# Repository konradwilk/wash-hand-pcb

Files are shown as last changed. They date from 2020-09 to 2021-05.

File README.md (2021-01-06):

# License

The project is under Attribution-ShareAlike 4.0 International (CC BY-SA 4.0).

# Libraries used for this project

 - adafruit
 - darnok\_common (https://github.com/konradwilk/eagle-libraries.git)
 - darnok\_led (https://github.com/konradwilk/eagle-libraries.git)
 - darnok\_usb (https://github.com/konradwilk/eagle-libraries.git)
 - darnok\_sensors (https://github.com/konradwilk/eagle-libraries.git)
 - darnok\_microsd (https://github.com/konradwilk/eagle-libraries.git)
 - darnok\_4050 (https://github.com/konradwilk/eagle-libraries.git)
 - SparkFun-Aesthetics
 - SparkFun-Capacitors
 - SparkFun-Connectors
 - SparkFun-Hardware
 - SparkFun-IC-Microcontroller
 - SparkFun-IC-Power
 - SparkFun-Jumpers
 - Serial-Basic (https://github.com/sparkfun/Serial_Basic_Breakout-CH340G.git)

# Purpose

Quite simply it is to have a count-down timer for 20 seconds for washing hands.
It is activated by a line sensor (which has infrared light) that plugs in the board.

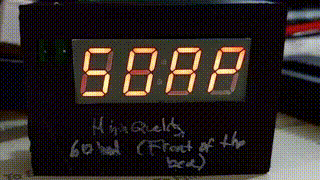
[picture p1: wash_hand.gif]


Video (speed up) of text printed.

# PCB

The _main_ branch is for development and changes often.
The <a href="Wash_Hand.pdf">Wash Hand</a> Board and Schematic are available.

## Prior versions

There are various branches, see:

 - <a href="https://github.com/konradwilk/wash-hand-pcb/tree/stable-1.3-tqfp">stable-1.3-tqfp</a>
 - <a href="https://github.com/konradwilk/wash-hand-pcb/tree/stable-1.3-dip28">stable-1.3-dip28</a>
 - <a href="https://github.com/konradwilk/wash-hand-pcb/tree/stable-1.2-dip28">stable-1.2-dip28</a>

# Future plans for software

In particular order:

 - Fetch data from a SD-card (if attached), otherwise read from EEPROM (1K).
 - Format-type of the data type for above mechanism.
 - Utilize sleep operations to keep the CPU most of the time asleep.
 - Utilize modulo for the numbers.

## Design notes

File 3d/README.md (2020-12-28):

# Create a board outline STL file
 
The release.sh release creates a SVG (and BMP) file which
has the outline of the board.

This can converted to STL files for helping to create
a box for it.

The sequence is as follow:

- Install Inkscape 0.92 (don't use 1.01) as the extension does not work
  with later versions.

- Install in .config/inkscape/extensions the
  https://github.com/l0b0/paths2openscad.git extension
  (the .py and .inx file).

- In Inkscape import the SVG file (created from the
  release.sh - the h-<release>.svg file. (See Wash_Hand_dim.svg)

- Select All

- Object|Ungroup

- Extensions|Generate from Path|Paths to OpenSCAD
- Output file Wash_Hand_dim.scad, keep the defaults, let it rip

- In OpenSCAD, load it, edit it (change height, etc) and render (F6) it,
  and Export as STL (F7) as Wash_Hand_dim.stl

- Then you have a 3D-ish presentation of what outline of the board
  and can use it to create boxes for the board.

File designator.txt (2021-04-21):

Y1
LED1
C14
C12
C13
Y2
RX
TX
R20
R19
R16
C4
C3
C16
C15
R9
R15
R1
R2
R3
R4
R5
R6
R7
R14
R12
TM1
IC1
R17
U2
LED2
T1
U1
U$4

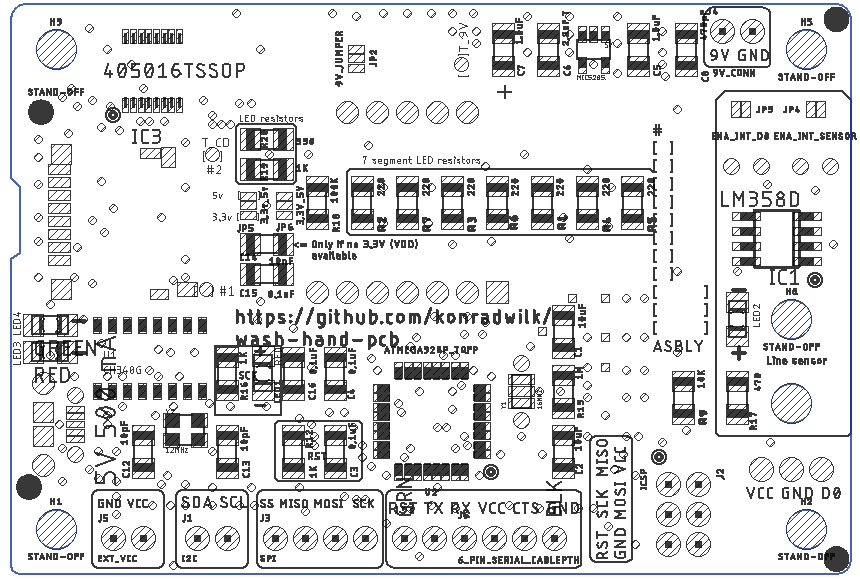
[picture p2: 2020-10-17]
v1.4-rc1/t-v1.4-rc1.png

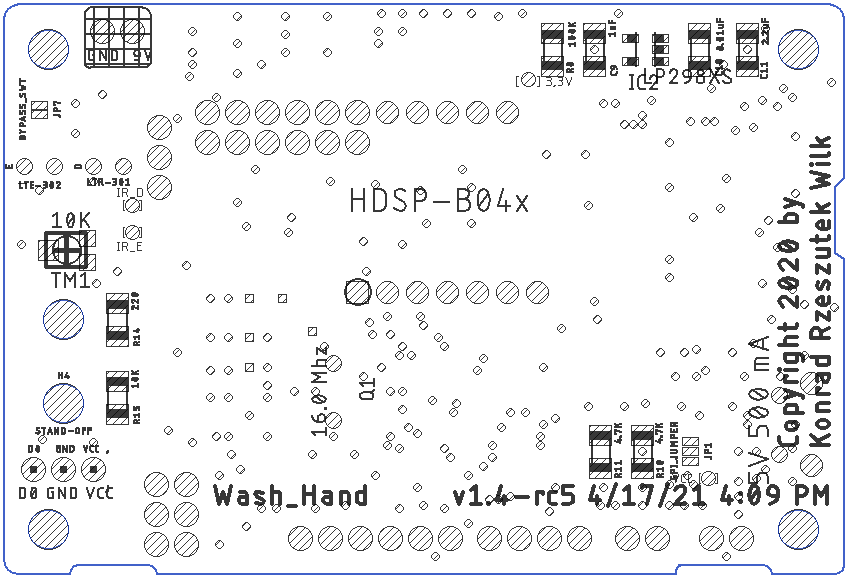
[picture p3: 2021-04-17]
v1.4-rc5/b-v1.4-rc5.png

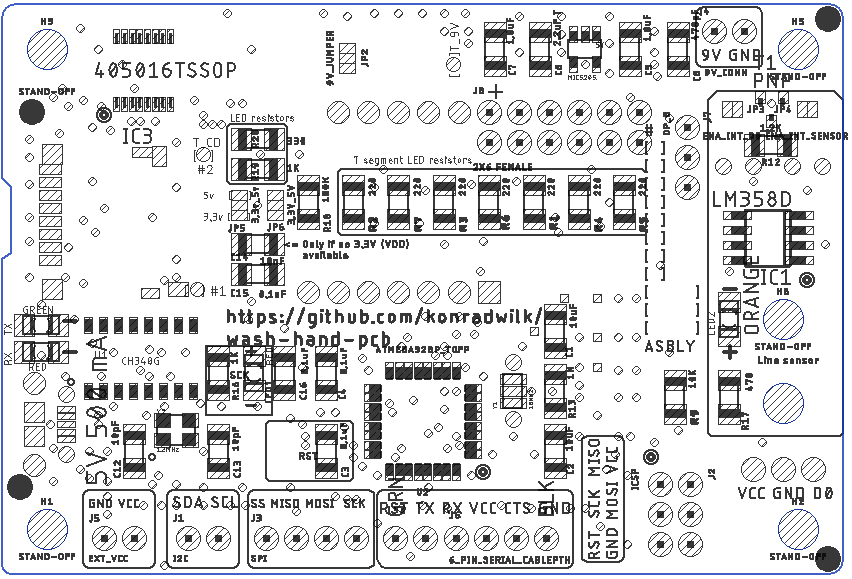
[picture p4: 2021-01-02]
v1.4-rc4/t-v1.4-rc4.png

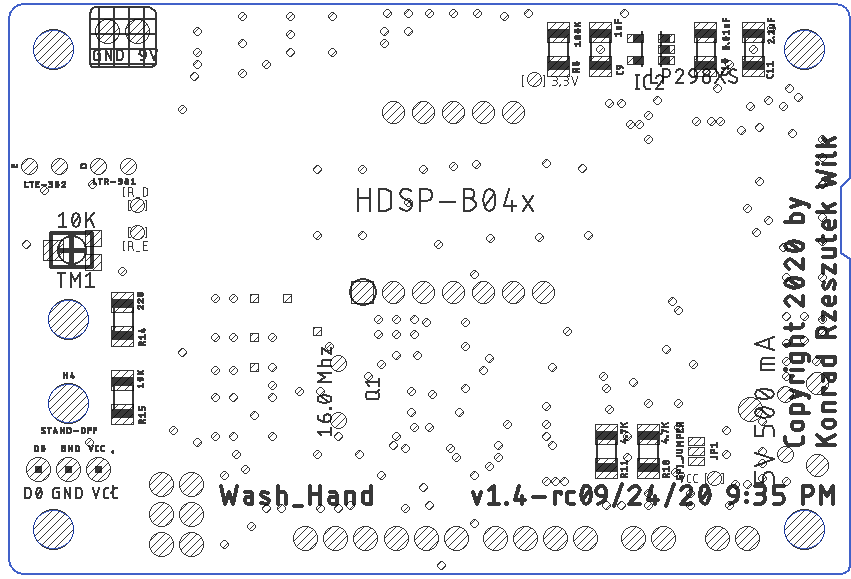
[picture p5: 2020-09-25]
v1.4-rc0/b-v1.4-rc0.png

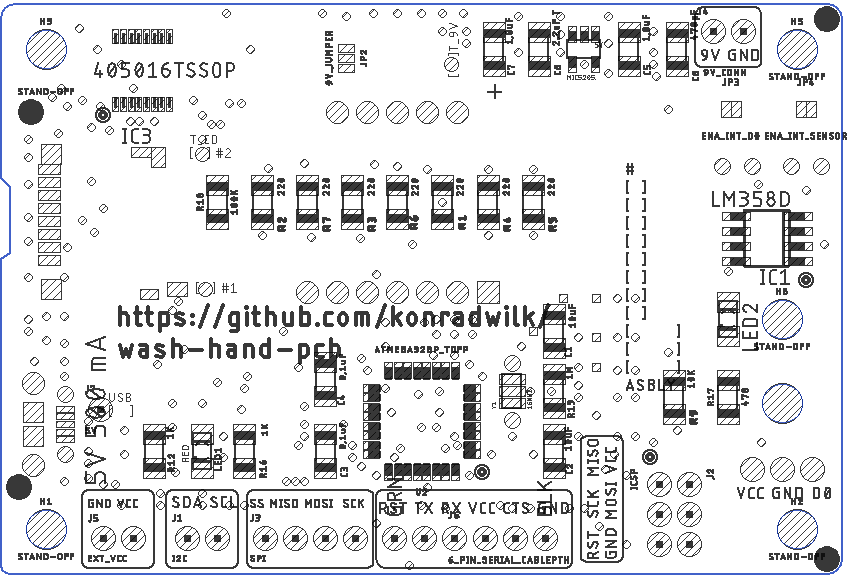
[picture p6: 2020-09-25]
v1.4-rc0/t-v1.4-rc0.png

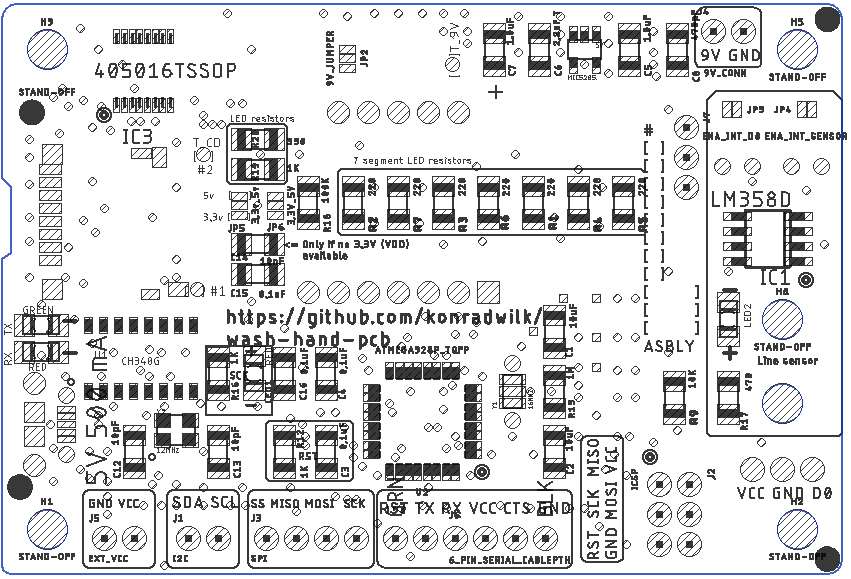
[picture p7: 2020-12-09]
v1.4-rc2/t-v1.4-rc2.png

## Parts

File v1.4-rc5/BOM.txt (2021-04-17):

Partlist exported from /home/konrad/eagle-projects/COVID19-WashHands/Hardware/Wash_Hand.sch at 4/17/21 4:09 PM

Qty Value                        Device                       Package                      Parts                           Description                                                                                                                                                                                                                                             HDSP-B04E MF MPN         OC_FARNELL OC_NEWARK POPULARITY PROD_ID    VALUE          
1   0.01uF                       1.0UF-1206-50V-10%           1206                         C10                             1µF ceramic capacitors                                                                                                                                                                                                                                                                                           CAP-09822  1.0uF          
2   0.1uF                        1.0UF-1206-50V-10%           1206                         C3, C4                          1µF ceramic capacitors                                                                                                                                                                                                                                                                                           CAP-09822  1.0uF          
2   0.1uF                        10UF-1206-6.3V-20%           1206                         C15, C16                        10.0µF ceramic capacitors                                                                                                                                                                                                                                                                                        CAP-10057  10uF           
1   1.2K                         RESISTORR1206                1206                         R12                                                                                                                                                                                                                                                                                                                                                                        
2   100K                         RESISTORR1206                1206                         R8, R18                                                                                                                                                                                                                                                                                                                                                                    
2   10K                          RESISTORR1206                1206                         R9, R15                                                                                                                                                                                                                                                                                                                                                                    
1   10K                          TRIMPOTTC33X                 TC33X                        TM1                             SMT trimmer potentiometer part number TC33X                                                                                                                                                                                                                                                                                                
1   10nF                         10UF-1206-6.3V-20%           1206                         C14                             10.0µF ceramic capacitors                                                                                                                                                                                                                                                                                        CAP-10057  10uF           
4   10pF                         10UF-1206-6.3V-20%           1206                         C1, C2, C12, C13                10.0µF ceramic capacitors                                                                                                                                                                                                                                                                                        CAP-10057  10uF           
1   114-00841-68                 114-00841-68                 114-00841-68                 MICROSD                         Amphenol MicroSD Push Pull                                                                                                                                                                                                                                                                                                                 
1   12MHz                        CRYSTAL-GROUNDED3.2X2.5      CRYSTAL-SMD-3.2X2.5          Y2                              Small, 3.2x2.5mm, SMD Crystal                                                                                                                                                                                                                                                                                    XTAL-13518 12MHz          
1   16.0 Mhz                     CRYSTALHC49S                 HC49/S                       Q1                              CRYSTAL                                                                                                                                                                                                                                                                          1667008    unknown                                        
1   16MHZ                        RESONATORMU                  RESONATOR                    Y1                                                                                                                                                                                                                                                                                                                                                                         
2   1K                           RESISTORR1206                1206                         R16, R19                                                                                                                                                                                                                                                                                                                                                                   
1   1M                           RESISTORR1206                1206                         R13                                                                                                                                                                                                                                                                                                                                                                        
3   1uF                          1.0UF-1206-50V-10%           1206                         C5, C7, C9                      1µF ceramic capacitors                                                                                                                                                                                                                                                                                           CAP-09822  1.0uF          
1   2.2uF                        1.0UF-1206-50V-10%           1206                         C11                             1µF ceramic capacitors                                                                                                                                                                                                                                                                                           CAP-09822  1.0uF          
1   2.2uF T                      1.0UF-1206-50V-10%           1206                         C6                              1µF ceramic capacitors                                                                                                                                                                                                                                                                                           CAP-09822  1.0uF          
8   220                          RESISTORR1206                1206                         R1, R2, R3, R4, R5, R6, R7, R14                                                                                                                                                                                                                                                                                                                                            
1   2X6 FEMALE                   CONN_06X2PTH_FEMALE          2X6                          J8                              Multi connection point. Often used as Generic Header-pin footprint for 0.1 inch spaced/style header connections                                                                                                                                                                                                  CONN-12423 2X6 FEMALE     
1   3.3V_5V                      JUMPER-SMT_3_2-NC_PASTE_SILK SMT-JUMPER_3_2-NC_PASTE_SILK JP6                             Normally closed solder jumper (2 of 2 connections)                                                                                                                                                                                                                                                                                         
1   3.3v_5v                      JUMPER-SMT_3_2-NC_PASTE_SILK SMT-JUMPER_3_2-NC_PASTE_SILK JP5                             Normally closed solder jumper (2 of 2 connections)                                                                                                                                                                                                                                                                                         
1   330                          RESISTORR1206                1206                         R20                                                                                                                                                                                                                                                                                                                                                                        
2   4.7K                         RESISTORR1206                1206                         R10, R11                                                                                                                                                                                                                                                                                                                                                                   
1   405016TSSOP                  405016TSSOP                  TSSOP16                      IC3                             Hex non-inverting BUFFER                                                                                                                                                                                                                                                                                                                   
1   470                          RESISTORR1206                1206                         R17                                                                                                                                                                                                                                                                                                                                                                        
1   470pF                        1.0UF-1206-50V-10%           1206                         C8                              1µF ceramic capacitors                                                                                                                                                                                                                                                                                           CAP-09822  1.0uF          
1   5V                           V_REG_MIC52055V              SOT23-5                      MIC5205                         V_REG MIC5205 Standard 3.3V, 5V, and Adjustable 150mA LDO voltage regulator in SOT-23 layout. Micrel part MIC5205. BP (by-pass) pin is used to lower output noise with 470pF cap, may be left open. On the adjustable version BP is used to set output.                                                          VREG-00823 5V             
1   6_PIN_SERIAL_CABLEPTH        6_PIN_SERIAL_CABLEPTH        FTDI_BASIC                   J6                              6-pin header connection for use with the "FTDI BASIC" pinout - CABLE SIDE.                                                                                                                                                                                                                                                                 
1   9V_CONN                      CONN_02                      1X02                         J4                              Multi connection point. Often used as Generic Header-pin footprint for 0.1 inch spaced/style header connections                                                                                                                                                                                                                            
1   9V_JUMPER                    JUMPER-SMT_3_2-NC_PASTE_SILK SMT-JUMPER_3_2-NC_PASTE_SILK JP2                             Normally closed solder jumper (2 of 2 connections)                                                                                                                                                                                                                                                                                         
1   ATMEGA328P_TQFP              ATMEGA328P_TQFP              TQFP32-08                    U2                              Popular 328P in QFP                                                                                                                                                                                                                                                                                              IC-09069   ATMEGA328P_TQFP
1   BYPASS_SWT                   JUMPER-SMT_2_NO_SILK         SMT-JUMPER_2_NO_SILK         JP7                             Normally open jumper                                                                                                                                                                                                                                                                                                                       
1   CH340G                       CH340GSMD                    SO016                        U1                              A simple USB 2.0 to Serial IC.                                                                                                                                                                                                                                                                                   IC-13498   CH340G         
1   D0    GND  VCC  ,            CONN_03                      1X03                         J                               Multi connection point. Often used as Generic Header-pin footprint for 0.1 inch spaced/style header connections                                                                                                                                                                                                                            
1   ENA_INT_D0                   JUMPER-SMT_2_NC_PASTE_SILK   SMT-JUMPER_2_NC_PASTE_SILK   JP3                             Normally closed solder jumper                                                                                                                                                                                                                                                                                                              
1   ENA_INT_SENSOR               JUMPER-SMT_2_NC_PASTE_SILK   SMT-JUMPER_2_NC_PASTE_SILK   JP4                             Normally closed solder jumper                                                                                                                                                                                                                                                                                                              
1   EXT_VCC                      CONN_02                      1X02                         J5                              Multi connection point. Often used as Generic Header-pin footprint for 0.1 inch spaced/style header connections                                                                                                                                                                                                                            
4   FIDUCIAL                     FIDUCIAL                     FIDUCIAL_1MM                 U$7, U$8, U$9, U$10             For use by pick and place machines to calibrate the vision/machine, 1mm                                                                                                                                                                                                                                                                    
1   GREEN                        LEDSMT1206                   1206                         TX                              LED                                                                                                                                                                                                                                                                                                                                        
1   HAPPY_FACE_LOGO              HAPPY_FACE_LOGO              HAPPY_FACE_LOGO              LOGO2                                                                                                                                                                                                                                                                                                                                                                      
1   HDSP-B04E                    HDSP-B04E                    HDSP-B0XE                    U$5                             7 Segment LED light 0.56"                                                                                                                                                                                                                                                                                                                  
1   I2C                          CONN_02                      1X02                         J1                              Multi connection point. Often used as Generic Header-pin footprint for 0.1 inch spaced/style header connections                                                                                                                                                                                                                            
1   ICSP                         CONN_03X2FEMALE              2X3                          J2                              Multi connection point. Often used as Generic Header-pin footprint for 0.1 inch spaced/style header connections                                                                                                                                                                                                  CONN-11566 FEMALE 2x3     
1   LM358D                       LM358D                       SO08                         IC1                             OP AMP also LM158; LM258; LM2904                                                                                                                                                                                                                                                                      12                                   
1   LP298XS                      LP298XS                      SOT23-5L                     IC2                                                                                                                                                                                                                                                                                                                                                                        
1   LTE-302                      LTE-302                      LTE-302                      E                                                                                                                                                                                                                                                                                                                                                                          
1   LTR-301                      LTR-301                      LTR-301                      D                                                                                                                                                                                                                                                                                                                                                                          
1   MMBT3904                     NPNSOT23                     SOT-23                       T1                              NPN TRANSISTOR                                                                                                                                                                                                                                                       DSS20201L-7 1710688    25R4555   0                                    
1   OP_B                         CONN_03                      1X03                         J7                              Multi connection point. Often used as Generic Header-pin footprint for 0.1 inch spaced/style header connections                                                                                                                                                                                                                            
1   ORANGE                       LEDSMT1206                   1206                         LED2                            LED                                                                                                                                                                                                                                                                                                                                        
1   OSHW-LOGOM                   OSHW-LOGOM                   OSHW-LOGO-M                  LOGO1                           Open-Source Hardware (OSHW) Logo                                                                                                                                                                                                                                                                                                           
2   RED                          LEDSMT1206                   1206                         LED1, RX                        LED                                                                                                                                                                                                                                                                                                                                        
1   SPI                          CONN_04                      1X04                         J3                              Multi connection point. Often used as Generic Header-pin footprint for 0.1 inch spaced/style header connections                                                                                                                                                                                                  CONN-09696                
1   SPI_JUMPER                   JUMPER-SMT_3_2-NC_PASTE_SILK SMT-JUMPER_3_2-NC_PASTE_SILK JP1                             Normally closed solder jumper (2 of 2 connections)                                                                                                                                                                                                                                                                                         
6   STAND-OFF                    STAND-OFF                    STAND-OFF                    H1, H2, H3, H4, H5, H6          Stand Off                                                                                                                                                                                                                                                                                                                                  
1   T_33_VCC                     TEST-POINT3X4                PAD.03X.04                   TP7                             SparkFun Test Points                                                                                                                                                                                                                                                                                                                       
1   T_5V_VCC                     TEST-POINT3X4                PAD.03X.04                   TP1                             SparkFun Test Points                                                                                                                                                                                                                                                                                                                       
1   T_9V_VCC                     TEST-POINT3X4                PAD.03X.04                   TP5                             SparkFun Test Points                                                                                                                                                                                                                                                                                                                       
1   T_CD                         TEST-POINT3X4                PAD.03X.04                   TP6                             SparkFun Test Points                                                                                                                                                                                                                                                                                                                       
1   T_CD2                        TEST-POINT3X4                PAD.03X.04                   TP8                             SparkFun Test Points                                                                                                                                                                                                                                                                                                                       
1   T_IR_DET                     TEST-POINT3X4                PAD.03X.04                   TP3                             SparkFun Test Points                                                                                                                                                                                                                                                                                                                       
1   T_IR_E                       TEST-POINT3X4                PAD.03X.04                   TP4                             SparkFun Test Points                                                                                                                                                                                                                                                                                                                       
1   USB_MICROB_10118194_AMPHENOL USB_MICROB_10118194_AMPHENOL USB_MICROB_10118194_AMPHENOL U$4

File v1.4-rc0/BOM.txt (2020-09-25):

Partlist exported from /home/konrad/eagle-projects/COVID19-WashHands/Hardware/Wash_Hand.sch at 9/24/20 9:35 PM

Qty Value                        Device                       Package                      Parts                           Description                                                                                                                                                                                                                                             HDSP-B04E MF MPN OC_FARNELL OC_NEWARK POPULARITY PROD_ID    VALUE          
1                                LEDSMT1206                   1206                         LED2                            LED                                                                                                                                                                                                                                                                                                                                
1   0.01uF                       1.0UF-1206-50V-10%           1206                         C10                             1µF ceramic capacitors                                                                                                                                                                                                                                                                                   CAP-09822  1.0uF          
2   0.1uF                        1.0UF-1206-50V-10%           1206                         C3, C4                          1µF ceramic capacitors                                                                                                                                                                                                                                                                                   CAP-09822  1.0uF          
2   100K                         RESISTORR1206                1206                         R8, R18                                                                                                                                                                                                                                                                                                                                                            
2   10K                          RESISTORR1206                1206                         R9, R15                                                                                                                                                                                                                                                                                                                                                            
1   10K                          TRIMPOTTC33X                 TC33X                        TM1                             SMT trimmer potentiometer part number TC33X                                                                                                                                                                                                                                                                                        
2   10pF                         10UF-1206-6.3V-20%           1206                         C1, C2                          10.0µF ceramic capacitors                                                                                                                                                                                                                                                                                CAP-10057  10uF           
1   114-00841-68                 114-00841-68                 114-00841-68                 MICROSD                         Amphenol MicroSD Push Pull                                                                                                                                                                                                                                                                                                         
1   16.0 Mhz                     CRYSTALHC49S                 HC49/S                       Q1                              CRYSTAL                                                                                                                                                                                                                                                                  1667008    unknown                                        
1   16MHZ                        RESONATORMU                  RESONATOR                    Y1                                                                                                                                                                                                                                                                                                                                                                 
2   1K                           RESISTORR1206                1206                         R12, R16                                                                                                                                                                                                                                                                                                                                                           
1   1M                           RESISTORR1206                1206                         R13                                                                                                                                                                                                                                                                                                                                                                
3   1uF                          1.0UF-1206-50V-10%           1206                         C5, C7, C9                      1µF ceramic capacitors                                                                                                                                                                                                                                                                                   CAP-09822  1.0uF          
1   2.2uF                        1.0UF-1206-50V-10%           1206                         C11                             1µF ceramic capacitors                                                                                                                                                                                                                                                                                   CAP-09822  1.0uF          
1   2.2uF T                      1.0UF-1206-50V-10%           1206                         C6                              1µF ceramic capacitors                                                                                                                                                                                                                                                                                   CAP-09822  1.0uF          
8   220                          RESISTORR1206                1206                         R1, R2, R3, R4, R5, R6, R7, R14                                                                                                                                                                                                                                                                                                                                    
2   4.7K                         RESISTORR1206                1206                         R10, R11                                                                                                                                                                                                                                                                                                                                                           
1   405016TSSOP                  405016TSSOP                  TSSOP16                      IC3                             Hex non-inverting BUFFER                                                                                                                                                                                                                                                                                                           
1   470                          RESISTORR1206                1206                         R17                                                                                                                                                                                                                                                                                                                                                                
1   470pF                        1.0UF-1206-50V-10%           1206                         C8                              1µF ceramic capacitors                                                                                                                                                                                                                                                                                   CAP-09822  1.0uF          
1   5V                           CONN_01                      1X01                         J7                              Single connection point. Often used as Generic Header-pin footprint for 0.1 inch spaced/style header connections                                                                                                                                                                                                                   
1   5V                           V_REG_MIC52055V              SOT23-5                      MIC5205                         V_REG MIC5205 Standard 3.3V, 5V, and Adjustable 150mA LDO voltage regulator in SOT-23 layout. Micrel part MIC5205. BP (by-pass) pin is used to lower output noise with 470pF cap, may be left open. On the adjustable version BP is used to set output.                                                  VREG-00823 5V             
1   6_PIN_SERIAL_CABLEPTH        6_PIN_SERIAL_CABLEPTH        FTDI_BASIC                   J6                              6-pin header connection for use with the "FTDI BASIC" pinout - CABLE SIDE.                                                                                                                                                                                                                                                         
1   9V_CONN                      CONN_02                      1X02                         J4                              Multi connection point. Often used as Generic Header-pin footprint for 0.1 inch spaced/style header connections                                                                                                                                                                                                                    
1   9V_JUMPER                    JUMPER-SMT_3_2-NC_PASTE_SILK SMT-JUMPER_3_2-NC_PASTE_SILK JP2                             Normally closed solder jumper (2 of 2 connections)                                                                                                                                                                                                                                                                                 
1   ATMEGA328P_TQFP              ATMEGA328P_TQFP              TQFP32-08                    U2                              Popular 328P in QFP                                                                                                                                                                                                                                                                                      IC-09069   ATMEGA328P_TQFP
1   D0    GND  VCC  ,            CONN_03                      1X03                         J                               Multi connection point. Often used as Generic Header-pin footprint for 0.1 inch spaced/style header connections                                                                                                                                                                                                                    
1   ENA_INT_D0                   JUMPER-SMT_2_NC_PASTE_SILK   SMT-JUMPER_2_NC_PASTE_SILK   JP3                             Normally closed solder jumper                                                                                                                                                                                                                                                                                                      
1   ENA_INT_SENSOR               JUMPER-SMT_2_NC_PASTE_SILK   SMT-JUMPER_2_NC_PASTE_SILK   JP4                             Normally closed solder jumper                                                                                                                                                                                                                                                                                                      
1   EXT_VCC                      CONN_02                      1X02                         J5                              Multi connection point. Often used as Generic Header-pin footprint for 0.1 inch spaced/style header connections                                                                                                                                                                                                                    
4   FIDUCIAL                     FIDUCIAL                     FIDUCIAL_1MM                 U$7, U$8, U$9, U$10             For use by pick and place machines to calibrate the vision/machine, 1mm                                                                                                                                                                                                                                                            
1   HDSP-B04E                    HDSP-B04E                    HDSP-B0XE                    U$5                             7 Segment LED light 0.56"                                                                                                                                                                                                                                                                                                          
1   I2C                          CONN_02                      1X02                         J1                              Multi connection point. Often used as Generic Header-pin footprint for 0.1 inch spaced/style header connections                                                                                                                                                                                                                    
1   ICSP                         CONN_03X2FEMALE              2X3                          J2                              Multi connection point. Often used as Generic Header-pin footprint for 0.1 inch spaced/style header connections                                                                                                                                                                                          CONN-11566 FEMALE 2x3     
1   LM358D                       LM358D                       SO08                         IC1                             OP AMP also LM158; LM258; LM2904                                                                                                                                                                                                                                                              12                                   
1   LP298XS                      LP298XS                      SOT23-5L                     IC2                                                                                                                                                                                                                                                                                                                                                                
1   LTE-302                      LTE-302                      LTE-302                      E                                                                                                                                                                                                                                                                                                                                                                  
1   LTR-301                      LTR-301                      LTR-301                      D                                                                                                                                                                                                                                                                                                                                                                  
1   OSHW-LOGOM                   OSHW-LOGOM                   OSHW-LOGO-M                  LOGO1                           Open-Source Hardware (OSHW) Logo                                                                                                                                                                                                                                                                                                   
1   RED                          LEDSMT1206                   1206                         LED1                            LED
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

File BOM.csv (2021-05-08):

Item | Name | Qty | Manufacturer | Mfg Part # | Descriptor/Value | Package/Footprint | Instructions
1 | Y1 | 1 | Murata Electronics | CSTNE16M0V530000R0 | CERAMIC RES 16.0000MHZ 15PF SMD | SMD
2 | C14 | 1 | KEMET | C1206C103K5RAC7210 | CAP CER 10000PF 50V X7R 1206 | SMD 1206
3 | C12,C13 | 2 | KEMET | C1206C100K3HAC7800 | CAP CER 1206 10PF 25V ULTRA STAB | SMD 1206
4 | Y2 | 1 | TXC CORPORATION | 7V-12.000MAHE-T | CRYSTAL 12.0000MHZ 12PF SMD | 4-SMD
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

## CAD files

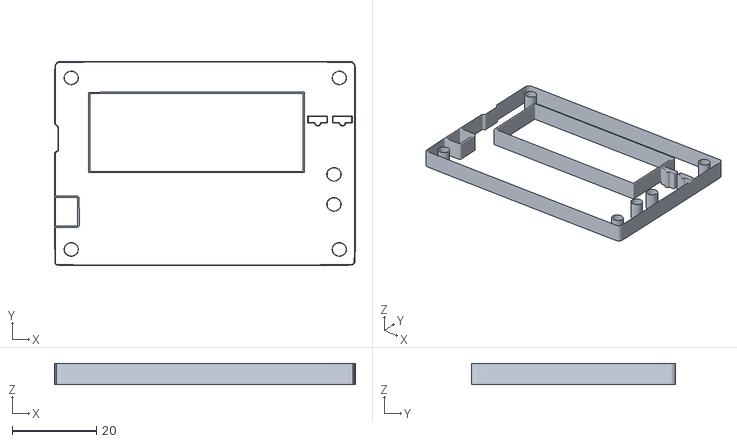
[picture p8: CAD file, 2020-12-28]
3d/Wash_Hand_dim.stl
71.3 x 48.4 x 5.00

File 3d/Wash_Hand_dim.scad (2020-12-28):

// Module names are of the form poly_<inkscape-path-id>().  As a result,
// you can associate a polygon in this OpenSCAD program with the corresponding
// SVG element in the Inkscape document by looking for the XML element with
// the attribute id="inkscape-path-id".

// fudge value is used to ensure that subtracted solids are a tad taller
// in the z dimension than the polygon being subtracted from.  This helps
// keep the resulting .stl file manifold.
fudge = 0.1;

module poly_path291(h)
{
  scale([25.4/90, -25.4/90, 1]) union()
  {
    difference()
    {
       linear_extrude(height=h)
         polygon([[86.176897,-36.915019],[86.176897,-33.915018],[89.026885,-33.915018],[91.284375,-33.828768],[91.876873,-33.495019],[92.619386,-32.201267],[94.126909,-31.335016],[95.112221,-31.313927],[96.001907,-31.593771],[96.734091,-32.149238],[97.246897,-32.955019],[97.696897,-33.915018],[100.336908,-33.915018],[102.976885,-33.915018],[102.976885,-36.915019],[102.976885,-39.915020],[94.576908,-39.915020],[86.176897,-39.915020]]);
       translate([0, 0, -fudge])
         linear_extrude(height=h+2*fudge)
           polygon([[102.376896,-36.915019],[102.376896,-34.515017],[99.706908,-34.515017],[97.036885,-34.515017],[96.826767,-33.645018],[96.036444,-32.332987],[94.734253,-31.901267],[93.375811,-32.341423],[92.416731,-33.645018],[92.116613,-34.515017],[89.446590,-34.515017],[86.776602,-34.515017],[86.776602,-36.915019],[86.776602,-39.315021],[94.576625,-39.315021],[102.376613,-39.315021]]);
    }
  }
}

module poly_path293(h)
{
  scale([25.4/90, -25.4/90, 1]) union()
  {
    difference()
    {
       linear_extrude(height=h)
         polygon([[106.876896,-36.915019],[106.876896,-33.915018],[109.726884,-33.915018],[111.984405,-33.828768],[112.576908,-33.495019],[113.319404,-32.201267],[114.826908,-31.335016],[115.812220,-31.313927],[116.701906,-31.593771],[117.434090,-32.149238],[117.946896,-32.955019],[118.396896,-33.915018],[121.036908,-33.915018],[123.676920,-33.915018],[123.676920,-36.915019],[123.676920,-39.915020],[115.276908,-39.915020],[106.876896,-39.915020]]);
       translate([0, 0, -fudge])
         linear_extrude(height=h+2*fudge)
           polygon([[123.076896,-36.915019],[123.076896,-34.515017],[120.406908,-34.515017],[117.736884,-34.515017],[117.526766,-33.645018],[116.736444,-32.332987],[115.434257,-31.901267],[114.075825,-32.341423],[113.116766,-33.645018],[112.816648,-34.515017],[110.146660,-34.515017],[107.476637,-34.515017],[107.476637,-36.915019],[107.476637,-39.315021],[115.276660,-39.315021],[123.076648,-39.315021]]);
    }
  }
}

module poly_path295(h)
{
  scale([25.4/90, -25.4/90, 1]) union()
  {
    difference()
    {
       linear_extrude(height=h)
         polygon([[105.406885,4.064995],[103.973456,4.983746],[102.984401,6.104996],[102.411594,7.473746],[102.226908,9.134996],[102.411594,10.796248],[102.984401,12.164999],[103.973456,13.286250],[105.406885,14.205001],[106.861895,14.778749],[108.226896,14.969999],[109.591898,14.778749],[111.046908,14.205001],[112.480337,13.286250],[113.469392,12.164999],[114.042199,10.796248],[114.226884,9.134996],[114.069429,7.413747],[113.416884,6.074996],[112.441418,5.006247],[111.125640,4.117497],[109.657988,3.509997],[108.226896,3.284996],[105.406885,4.064995]]);
       translate([0, 0, -fudge])
         linear_extrude(height=h+2*fudge)
           polygon([[111.106896,4.424995],[112.406271,5.339175],[113.334396,6.479058],[113.891271,7.769410],[114.076896,9.134997],[113.891271,10.500583],[113.334396,11.790936],[112.406271,12.930820],[111.106896,13.845001],[109.616268,14.469374],[108.226896,14.677499],[106.837525,14.469374],[105.346896,13.845001],[103.970641,12.926249],[103.066885,11.714999],[102.410646,9.601404],[102.609399,7.563747],[103.606898,5.779214],[105.346896,4.424995],[106.865651,3.802495],[108.226896,3.584994],[109.588142,3.802499],[111.106896,4.424995]]);
    }
  }
}

module poly_path283(h)
{
  scale([25.4/90, -25.4/90, 1]) union()
  {
    difference()
    {
       linear_extrude(height=h)
         polygon([[-122.773189,-85.575038],[-124.411941,-84.588787],[-125.623191,-82.995036],[-125.970066,-81.827848],[-126.148190,-78.697535],[-126.223190,-57.435026],[-126.223190,-33.135019],[-124.873190,-31.815017],[-123.523190,-30.495018],[-123.523190,-20.715012],[-123.523190,-10.965012],[-124.813191,-10.155008],[-126.133190,-9.315010],[-126.313190,16.095001],[-126.316896,60.232517],[-125.893191,84.165025],[-124.633188,85.305024],[-120.857406,85.568932],[-104.934432,85.706276],[-0.163145,85.725026],[106.771895,85.575026],[121.269397,85.395963],[124.156896,85.065025],[125.656920,83.565026],[125.975197,81.435494],[126.155658,71.636272],[126.316896,0.464995],[126.294307,-71.433782],[126.122767,-80.902067],[125.776896,-82.965038],[124.216920,-84.945038],[123.226920,-85.665038],[0.526858,-85.725026],[-122.773189,-85.575038]]);
       translate([0, 0, -fudge])
         linear_extrude(height=h+2*fudge)
           polygon([[123.196908,-84.795036],[124.906908,-83.385037],[125.626908,-82.365036],[125.626908,0.014995],[125.469452,75.386272],[124.994145,83.390180],[124.576121,84.200825],[124.006908,84.495024],[120.760338,84.795962],[105.571892,84.967525],[-0.073145,85.125024],[-96.939429,85.102475],[-124.213189,84.855024],[-125.353191,83.775024],[-125.623191,68.355020],[-125.623191,53.685013],[-116.263188,53.685013],[-108.054435,53.602513],[-106.783652,53.406576],[-106.213182,53.025015],[-105.523183,52.395012],[-105.523183,40.515008],[-105.605683,30.093756],[-105.801620,28.571724],[-106.183181,27.975004],[-106.813185,27.285005],[-116.233187,27.285005],[-125.623191,27.285005],[-125.623191,9.194999],[-125.623191,-8.865010],[-124.273188,-9.705008],[-122.923188,-10.575010],[-122.923188,-20.685015],[-122.923188,-30.795016],[-124.273188,-32.115018],[-125.623191,-33.465018],[-125.563203,-57.915027],[-125.473203,-82.365036],[-124.753203,-83.385037],[-123.103202,-84.795036],[-84.230687,-85.136755],[0.024348,-85.256287],[84.290636,-85.145192],[123.196908,-84.795036]]);
       translate([0, 0, -fudge])
         linear_extrude(height=h+2*fudge)
           polygon([[-106.873183,40.485011],[-106.873183,52.335013],[-116.083188,52.425013],[-125.323190,52.485001],[-125.323190,40.484997],[-125.323190,28.484989],[-116.083188,28.544977],[-106.873183,28.634977]]);
    }
  }
}

module poly_path297(h)
{
  scale([25.4/90, -25.4/90, 1]) union()
  {
    difference()
    {
       linear_extrude(height=h)
         polygon([[105.406885,29.265005],[103.973456,30.183756],[102.984401,31.305006],[102.411594,32.673756],[102.226908,34.335006],[102.411594,35.996257],[102.984401,37.365008],[103.973456,38.486258],[105.406885,39.405007],[106.861895,39.978758],[108.226896,40.170008],[109.591898,39.978758],[111.046908,39.405007],[112.480337,38.486258],[113.469392,37.365008],[114.042199,35.996257],[114.226884,34.335006],[114.042199,32.673756],[113.469392,31.305006],[112.480337,30.183756],[111.046908,29.265005],[109.591898,28.691255],[108.226896,28.500004],[106.861895,28.691255],[105.406885,29.265005]]);
       translate([0, 0, -fudge])
         linear_extrude(height=h+2*fudge)
           polygon([[111.106896,29.625005],[112.406271,30.539185],[113.334396,31.679068],[113.891271,32.969420],[114.076896,34.335006],[113.891271,35.700593],[113.334396,36.990944],[112.406271,38.130828],[111.106896,39.045007],[109.616268,39.669383],[108.226896,39.877508],[106.837525,39.669383],[105.346896,39.045007],[103.970641,38.126258],[103.066885,36.915009],[102.410646,34.801413],[102.609399,32.763756],[103.606898,30.979224],[105.346896,29.625005],[106.865651,29.002505],[108.226896,28.785004],[109.588142,29.002509],[111.106896,29.625005]]);
    }
  }
}
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

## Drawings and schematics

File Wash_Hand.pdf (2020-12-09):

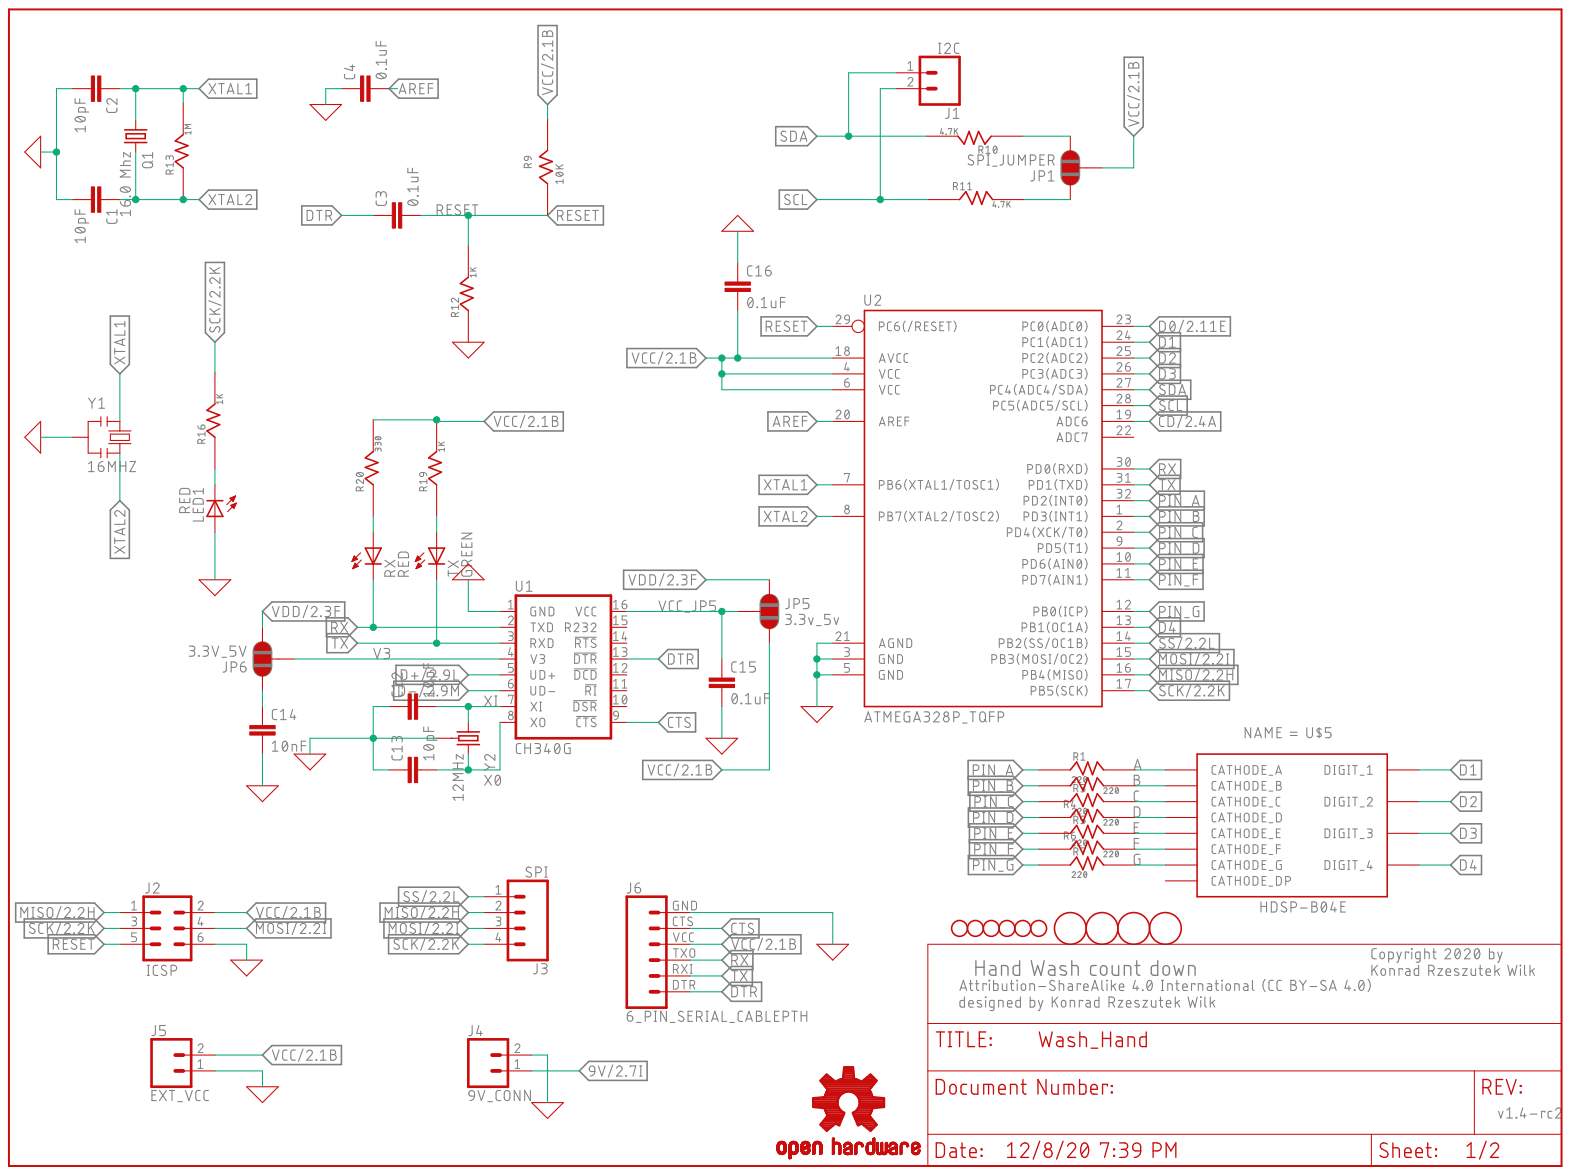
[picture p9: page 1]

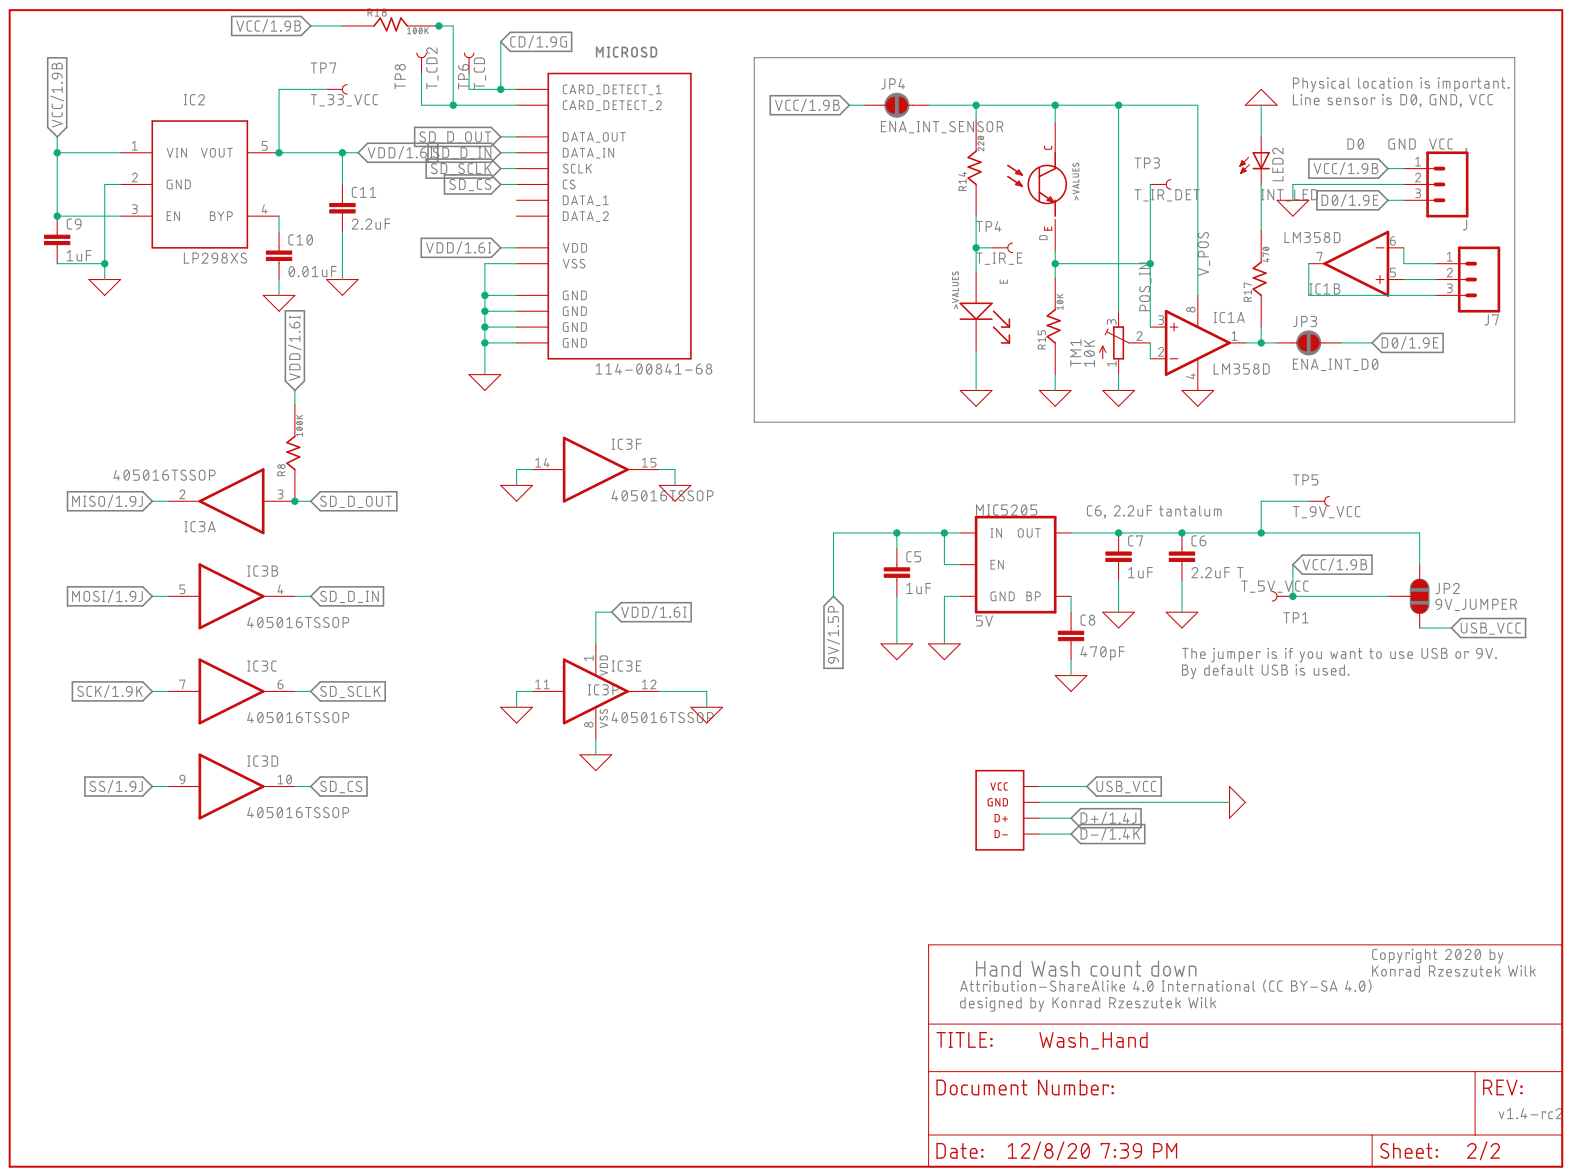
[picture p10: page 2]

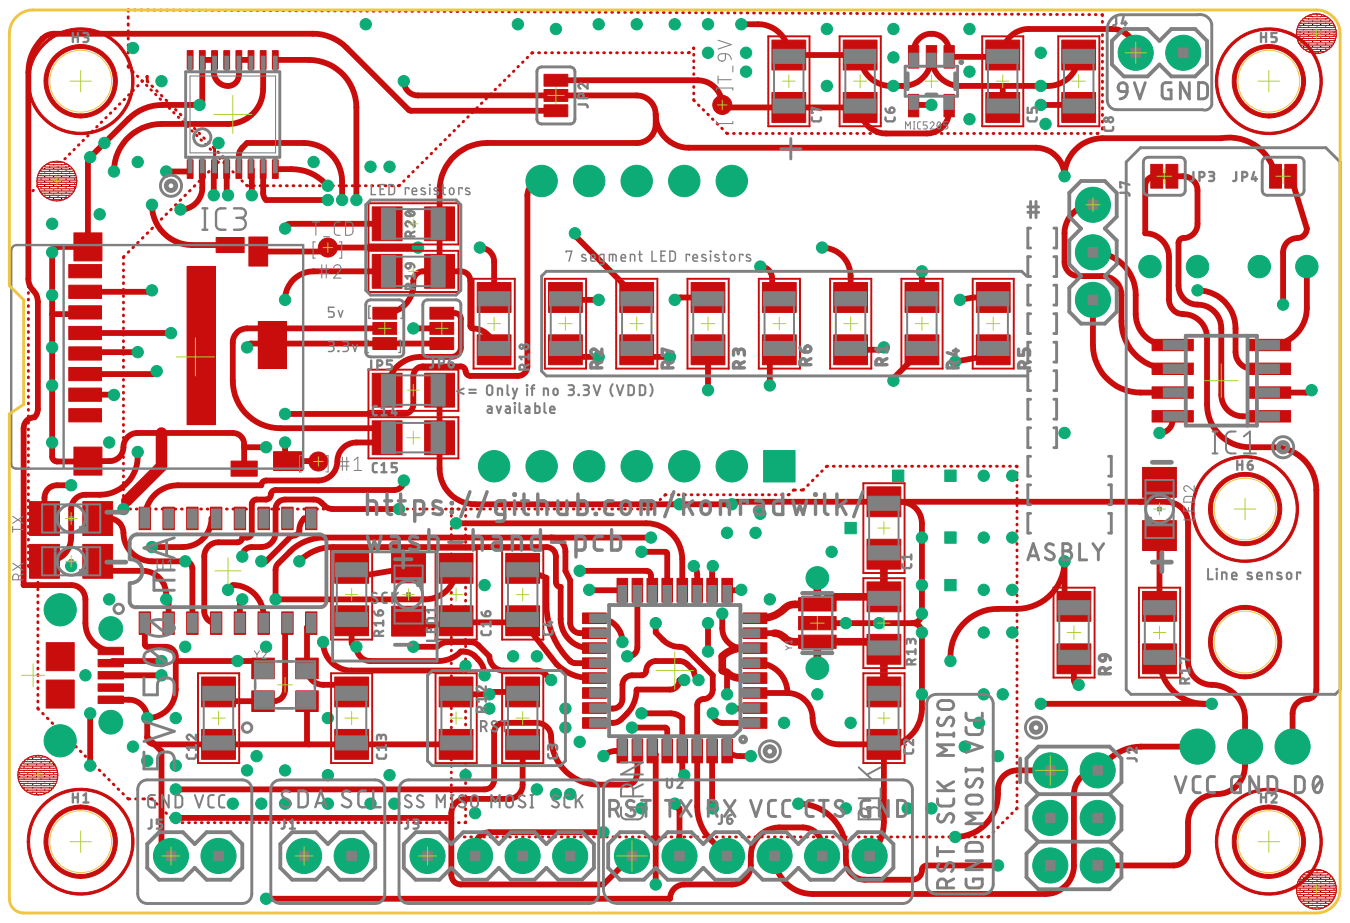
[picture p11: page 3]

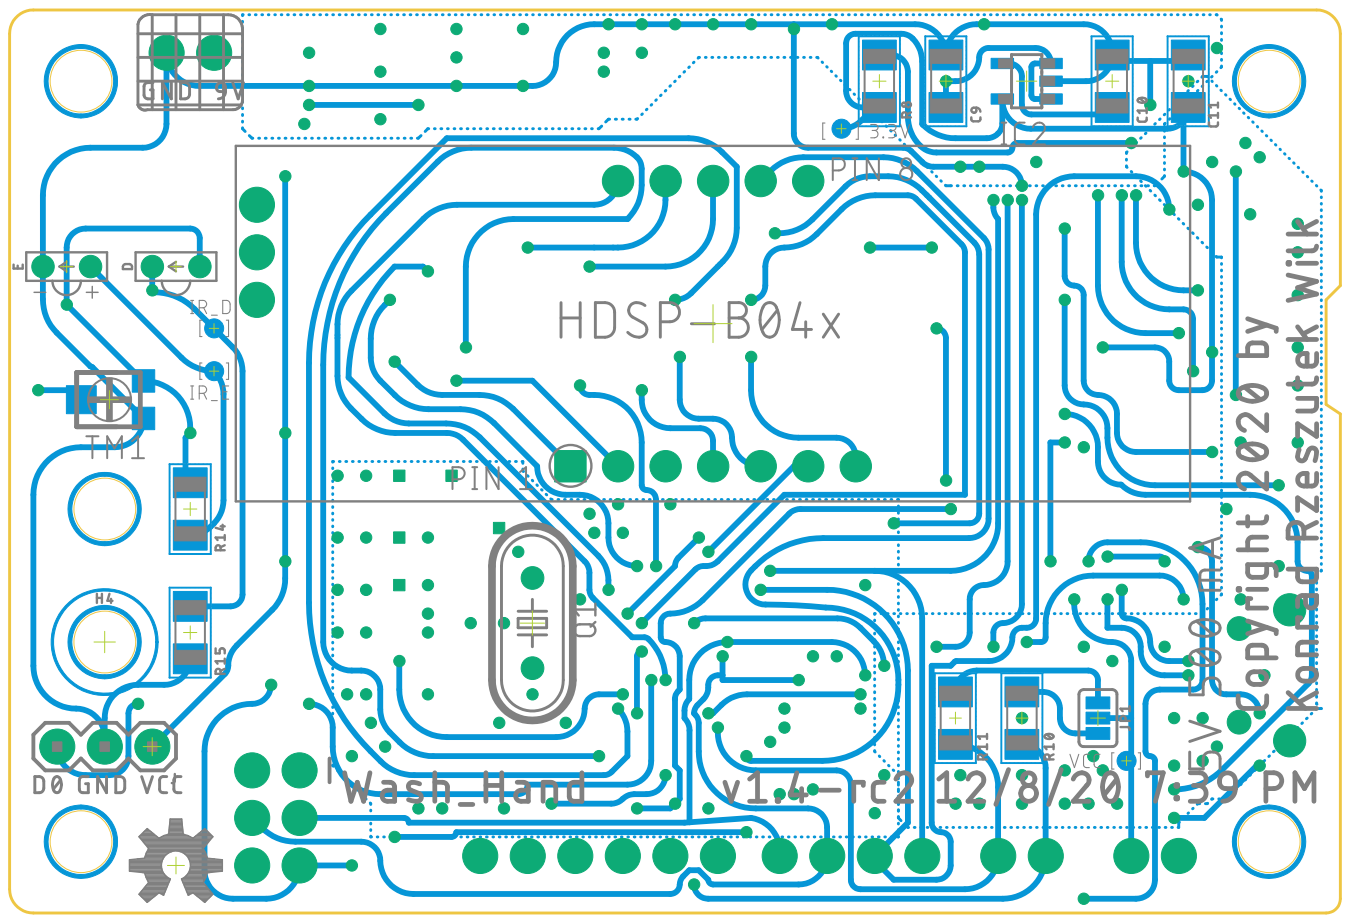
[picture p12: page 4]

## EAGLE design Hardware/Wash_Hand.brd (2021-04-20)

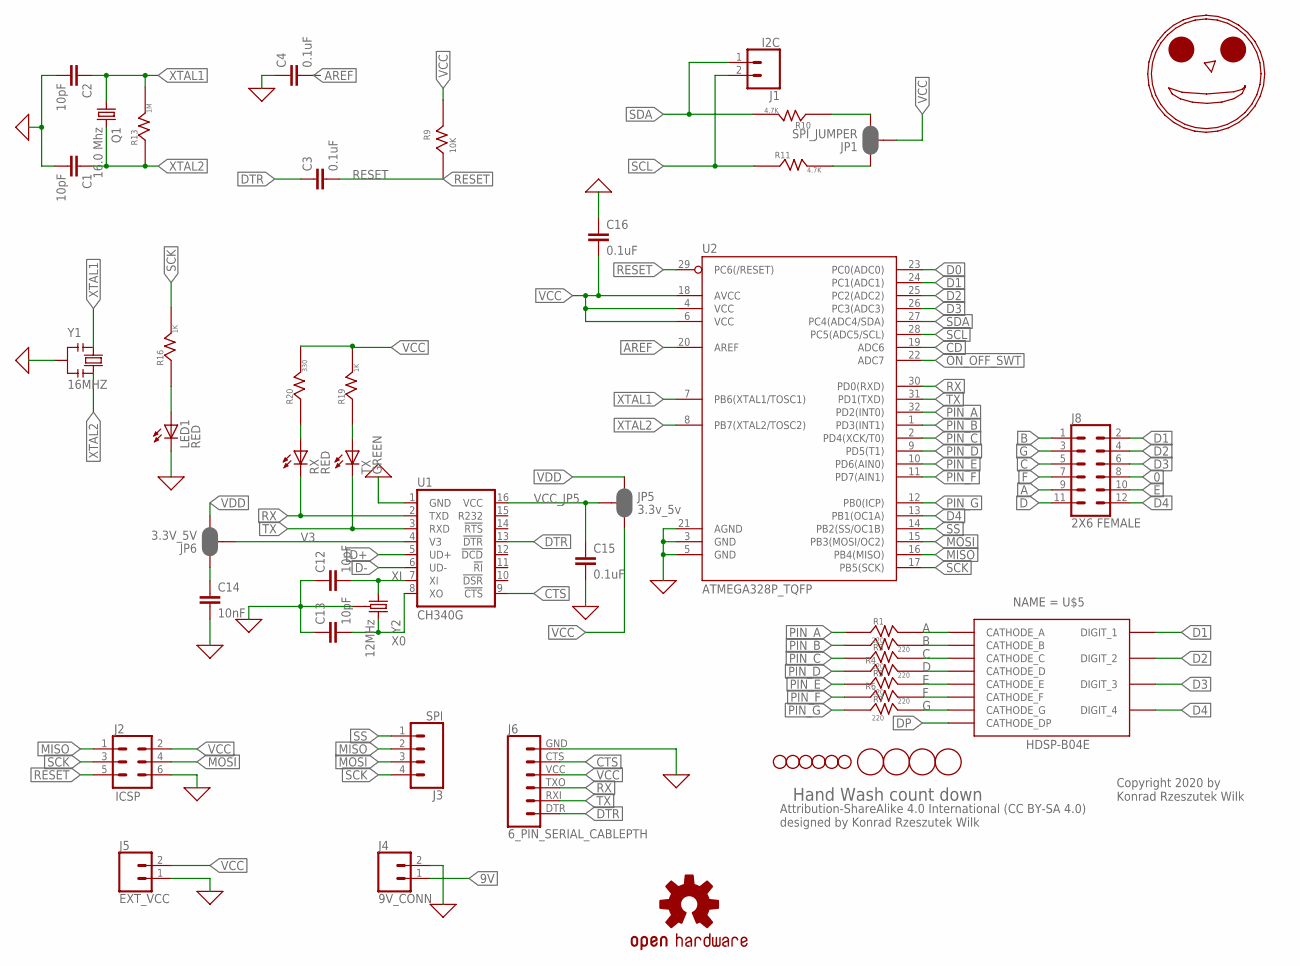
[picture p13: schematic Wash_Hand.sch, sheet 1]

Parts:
C1, C2, C12, C13: 10pF; 1206
C3, C4, C15, C16: 0.1uF; 1206
C14: 10nF; 1206
H1, H2, H3, H4, H5, H6: STAND-OFF
J1: I2C; 1X02
J2: ICSP; 2X3
J3: SPI; 1X04
J4: 9V_CONN; 1X02
J5: EXT_VCC; 1X02
J6: 6_PIN_SERIAL_CABLEPTH; FTDI_BASIC
J8: 2X6 FEMALE; 2X6
JP1: SPI_JUMPER; SMT-JUMPER_3_2-NC_PASTE_SILK
JP5: 3.3v_5v; SMT-JUMPER_3_2-NC_PASTE_SILK
JP6: 3.3V_5V; SMT-JUMPER_3_2-NC_PASTE_SILK
LED1: RED; 1206
LOGO1: OSHW-LOGOM; OSHW-LOGO-M
LOGO2: HAPPY_FACE_LOGO
Q1: 16.0 Mhz; HC49/S
R1, R2, R3, R4, R5, R6, R7: 220; 1206
R9: 10K; 1206
R10, R11: 4.7K; 1206
R13: 1M; 1206
R16, R19: 1K; 1206
R20: 330; 1206
RX: RED; 1206
TX: GREEN; 1206
U1: CH340G; SO016
U2: ATMEGA328P_TQFP; TQFP32-08
U$5: HDSP-B04E; HDSP-B0XE
U$7, U$8, U$9, U$10: FIDUCIAL; FIDUCIAL_1MM
Y1: 16MHZ; RESONATOR
Y2: 12MHz; CRYSTAL-SMD-3.2X2.5

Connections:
0: C1.2, C2.2, C4.1, C12.1, C13.1, C14.2, C15.2, C16.1, J2.6, J4.2, J5.1, J6.GND (6), J8.8, LED1.C, U1.1 (GND), U2.3 (GND), U2.5 (GND), U2.21 (AGND), Y1.2, Y2.2 (GND), Y2.4 (GND); also elsewhere on the board
9V: J4.1; also elsewhere on the board
A: J8.9, R1.2 (R_2), U$5.PIN$11 (CATHODE_A)
AREF: C4.2, U2.20 (AREF)
B: J8.1, R2.2 (R_2), U$5.PIN$7 (CATHODE_B)
C: J8.5, R3.2 (R_2), U$5.PIN$4 (CATHODE_C)
CD: U2.19 (ADC6); also elsewhere on the board
CTS: J6.CTS (5), U1.9 (!CTS)
D: J8.11, R4.2 (R_2), U$5.PIN$2 (CATHODE_D)
D0: U2.23 (PC0(ADC0)); also elsewhere on the board
D1: J8.2, U2.24 (PC1(ADC1)), U$5.PIN12 (DIGIT_1)
D2: J8.4, U2.25 (PC2(ADC2)), U$5.PIN$9 (DIGIT_2)
D3: J8.6, U2.26 (PC3(ADC3)), U$5.PIN$8 (DIGIT_3)
D4: J8.12, U2.13 (PB1(OC1A)), U$5.PIN$6 (DIGIT_4)
D+: U1.5 (UD+); also elsewhere on the board
D-: U1.6 (UD-); also elsewhere on the board
DP: U$5.PIN$3 (CATHODE_DP)
DTR: C3.1, J6.DTR (1), U1.13 (!DTR)
E: J8.10, R5.2 (R_2), U$5.PIN$1 (CATHODE_E)
F: J8.7, R6.2 (R_2), U$5.PIN$10 (CATHODE_F)
G: J8.3, R7.2 (R_2), U$5.PIN$5 (CATHODE_G)
MISO: J2.1, J3.2, U2.16 (PB4(MISO)); also elsewhere on the board
MOSI: J2.4, J3.3, U2.15 (PB3(MOSI/OC2)); also elsewhere on the board
unnamed: JP1.3, R10.1 (R_1)
unnamed: JP1.1, R11.2 (R_2)
unnamed: LED1.A, R16.1 (R_1)
unnamed: R19.1 (R_1), TX.A
unnamed: R20.1 (R_1), RX.A
unnamed: C14.1, JP6.1
ON_OFF_SWT: U2.22 (ADC7); also elsewhere on the board
PIN_A: R1.1 (R_1), U2.32 (PD2(INT0))
PIN_B: R2.1 (R_1), U2.1 (PD3(INT1))
PIN_C: R3.1 (R_1), U2.2 (PD4(XCK/T0))
PIN_D: R4.1 (R_1), U2.9 (PD5(T1))
PIN_E: R5.1 (R_1), U2.10 (PD6(AIN0))
PIN_F: R6.1 (R_1), U2.11 (PD7(AIN1))
PIN_G: R7.1 (R_1), U2.12 (PB0(ICP))
RESET: C3.2, J2.5, R9.1 (R_1), U2.29 (PC6(/RESET))
RX: J6.TXO (3), RX.C, U1.2 (TXD), U2.30 (PD0(RXD))
SCK: J2.3, J3.4, R16.2 (R_2), U2.17 (PB5(SCK)); also elsewhere on the board
SCL: J1.2, R11.1 (R_1), U2.28 (PC5(ADC5/SCL))
SDA: J1.1, R10.2 (R_2), U2.27 (PC4(ADC4/SDA))
SS: J3.1, U2.14 (PB2(SS/OC1B)); also elsewhere on the board
TX: J6.RXI (2), TX.C, U1.3 (RXD), U2.31 (PD1(TXD))
V3: JP6.2, U1.4 (V3)
VCC: C16.2, J2.2, J5.2, J6.VCC (4), JP1.2, JP5.3, R9.2 (R_2), R19.2 (R_2), R20.2 (R_2), U2.4 (VCC), U2.6 (VCC), U2.18 (AVCC); also elsewhere on the board
VCC_JP5: C15.1, JP5.2, U1.16 (VCC)
VDD: JP5.1, JP6.3; also elsewhere on the board
X0: C13.2, U1.8 (XO), Y2.3 (2)
XI: C12.2, U1.7 (XI), Y2.1
XTAL1: C2.1, Q1.1, R13.2 (R_2), U2.7 (PB6(XTAL1/TOSC1)), Y1.1
XTAL2: C1.1, Q1.2, R13.1 (R_1), U2.8 (PB7(XTAL2/TOSC2)), Y1.3

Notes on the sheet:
Hand Wash count down
Copyright 2020 by Konrad Rzeszutek Wilk
Attribution-ShareAlike 4.0 International (CC BY-SA 4.0) designed by Konrad Rzeszutek Wilk

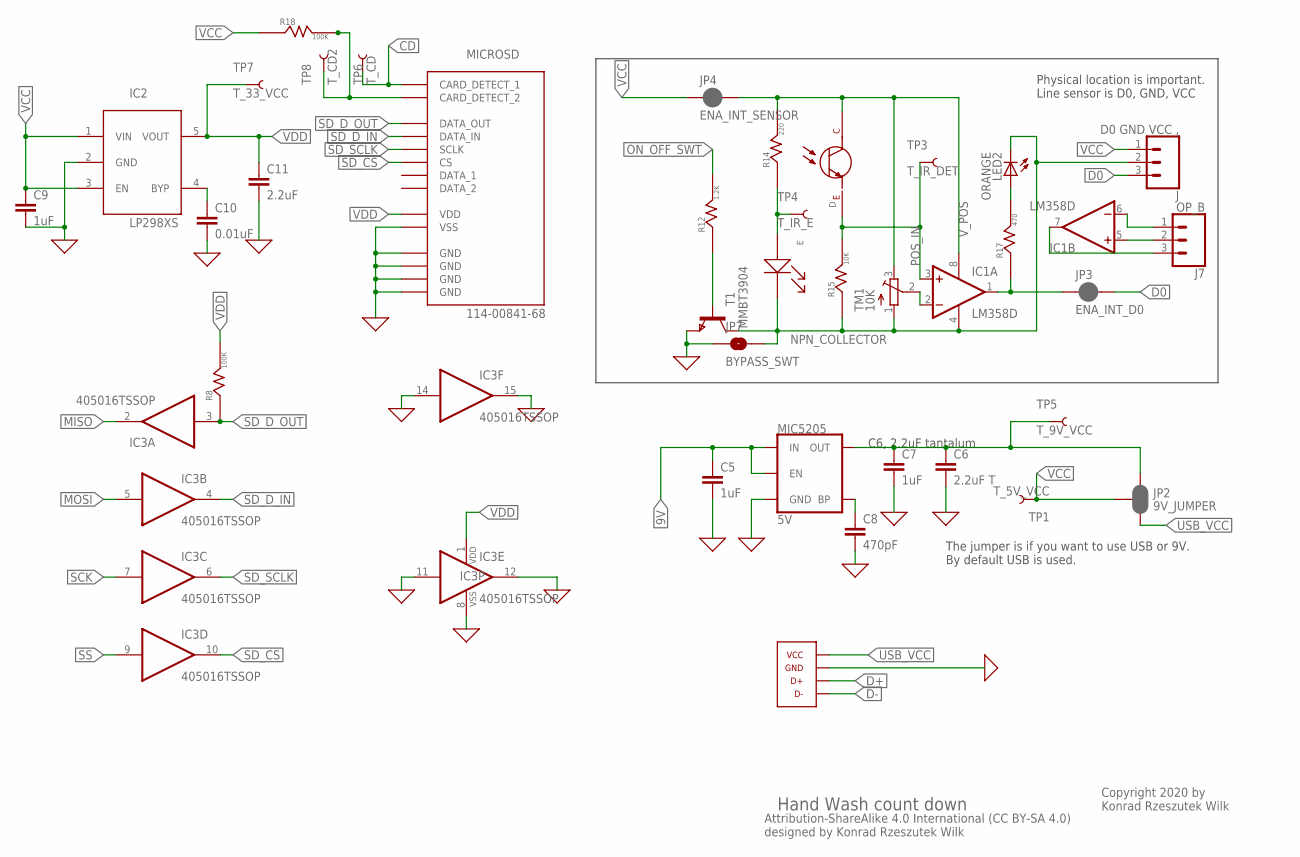
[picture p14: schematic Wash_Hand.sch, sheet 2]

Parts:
C5, C7, C9: 1uF; 1206
C6: 2.2uF T; 1206
C8: 470pF; 1206
C10: 0.01uF; 1206
C11: 2.2uF; 1206
D: LTR-301
E: LTE-302
IC1: LM358D; SO08
IC2: LP298XS; SOT23-5L
IC3: 405016TSSOP; TSSOP16
J: D0 GND VCC ,; 1X03
J7: OP_B; 1X03
JP2: 9V_JUMPER; SMT-JUMPER_3_2-NC_PASTE_SILK
JP3: ENA_INT_D0; SMT-JUMPER_2_NC_PASTE_SILK
JP4: ENA_INT_SENSOR; SMT-JUMPER_2_NC_PASTE_SILK
JP7: BYPASS_SWT; SMT-JUMPER_2_NO_SILK
LED2: ORANGE; 1206
MIC5205: 5V; SOT23-5
MICROSD: 114-00841-68
R8, R18: 100K; 1206
R12: 1.2K; 1206
R14: 220; 1206
R15: 10K; 1206
R17: 470; 1206
T1: MMBT3904; SOT-23
TM1: 10K; TC33X
TP1: T_5V_VCC; PAD.03X.04
TP3: T_IR_DET; PAD.03X.04
TP4: T_IR_E; PAD.03X.04
TP5: T_9V_VCC; PAD.03X.04
TP6: T_CD; PAD.03X.04
TP7: T_33_VCC; PAD.03X.04
TP8: T_CD2; PAD.03X.04
U$4: USB_MICROB_10118194_AMPHENOL

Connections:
0: C5.2, C6.2, C7.2, C8.2, C9.2, C10.2, C11.2, IC2.2 (GND), IC3.8 (VSS), IC3.11 (I), IC3.12 (O), IC3.14 (I), IC3.15 (O), JP7.1, MIC5205.2 (GND), MICROSD.GND$1 (GND), MICROSD.GND$2 (GND), MICROSD.GND$3 (GND), MICROSD.GND$4 (GND), MICROSD.VSS, T1.2 (E), U$4.5 (GND); also elsewhere on the board
9V: C5.1, MIC5205.1 (IN), MIC5205.3 (EN); also elsewhere on the board
CD: MICROSD.CD_SW_1 (CARD_DETECT_1), TP6.P$1; also elsewhere on the board
D0: IC1.1 (OUT), J.3, JP3.1, JP3.2, R17.1 (R_1); also elsewhere on the board
D+: U$4.3 (D+); also elsewhere on the board
D-: U$4.2 (D-); also elsewhere on the board
MISO: IC3.2 (O); also elsewhere on the board
MOSI: IC3.5 (I); also elsewhere on the board
unnamed: IC1.7 (OUT), J7.3
unnamed: MICROSD.CD_SW_2 (CARD_DETECT_2), R18.2 (R_2), TP8.P$1
unnamed: IC1.5 (+IN), J7.2
unnamed: C6.1, C7.1, JP2.1, MIC5205.5 (OUT), TP5.P$1
unnamed: E.A, R14.1 (R_1), TP4.P$1
unnamed: C10.1, IC2.4 (BYP)
unnamed: IC1.6 (-IN), J7.1
unnamed: LED2.A, R17.2 (R_2)
unnamed: R12.1 (R_1), T1.3 (B)
unnamed: C8.1, MIC5205.4 (BP)
NEG_IN: IC1.2 (-IN), TM1.2 (S)
NPN_COLLECTOR: E.C, IC1.4 (V-), J.2, JP7.2, LED2.C, R15.1 (R_1), T1.1 (C), TM1.1 (A)
ON_OFF_SWT: R12.2 (R_2); also elsewhere on the board
POS_IN: D.E, IC1.3 (+IN), R15.2 (R_2), TP3.P$1
SCK: IC3.7 (I); also elsewhere on the board
SD_CS: IC3.10 (O), MICROSD.CS
SD_D_IN: IC3.4 (O), MICROSD.DATA_IN
SD_D_OUT: IC3.3 (I), MICROSD.DATA_OUT, R8.1 (R_1)
SD_SCLK: IC3.6 (O), MICROSD.SCLK
SS: IC3.9 (I); also elsewhere on the board
USB_VCC: JP2.3, U$4.1 (VCC)
VCC: C9.1, IC2.1 (VIN), IC2.3 (EN), J.1, JP2.2, JP4.1, R18.1 (R_1), TP1.P$1; also elsewhere on the board
VDD: C11.1, IC2.5 (VOUT), IC3.1 (VDD), MICROSD.VDD, R8.2 (R_2), TP7.P$1; also elsewhere on the board
V_POS: D.C, IC1.8 (V+), JP4.2, R14.2 (R_2), TM1.3 (E)

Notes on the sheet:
Hand Wash count down
Copyright 2020 by Konrad Rzeszutek Wilk
Attribution-ShareAlike 4.0 International (CC BY-SA 4.0) designed by Konrad Rzeszutek Wilk
Physical location is important. Line sensor is D0, GND, VCC
The jumper is if you want to use USB or 9V. By default USB is used.
C6, 2.2uF tantalum

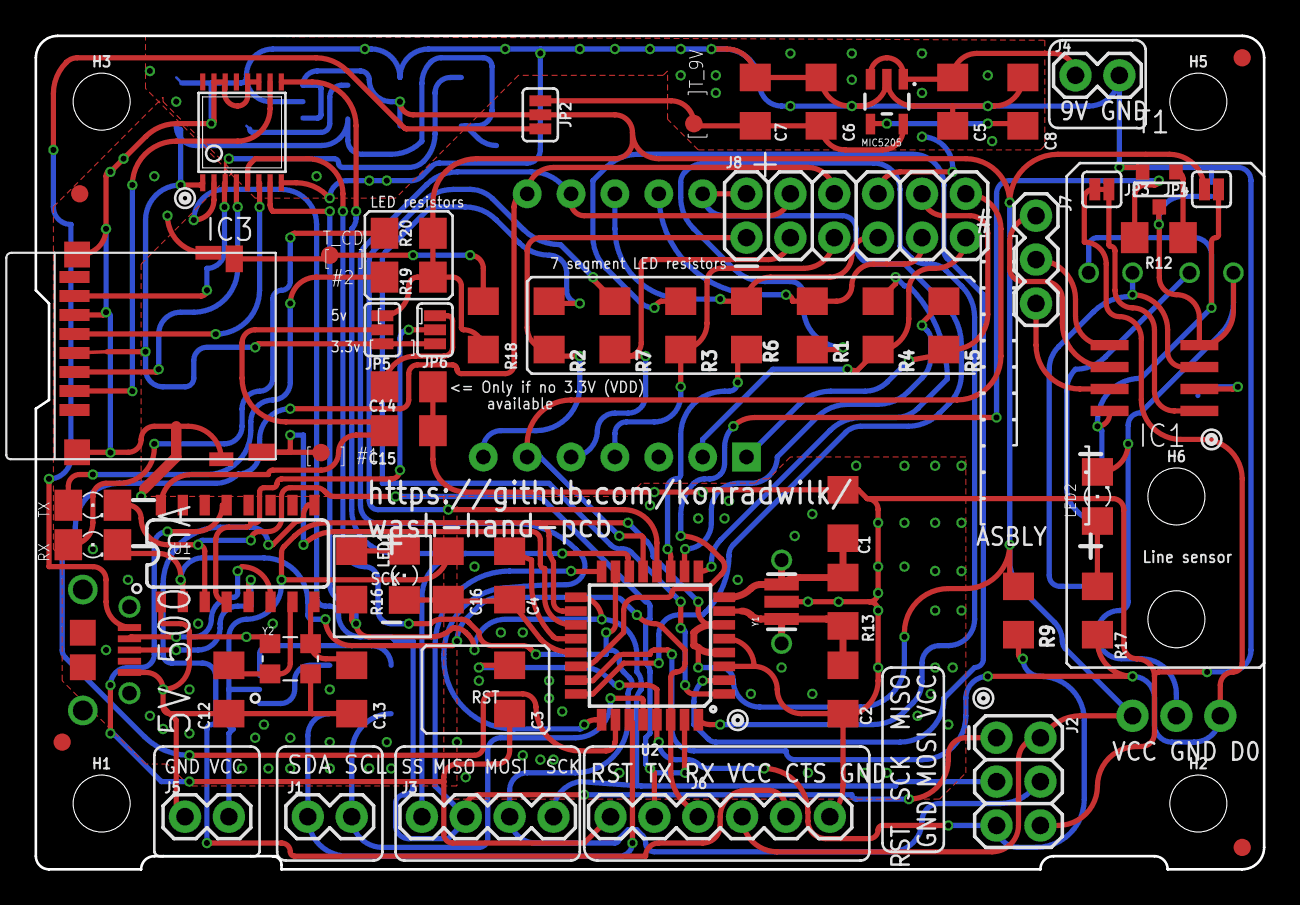
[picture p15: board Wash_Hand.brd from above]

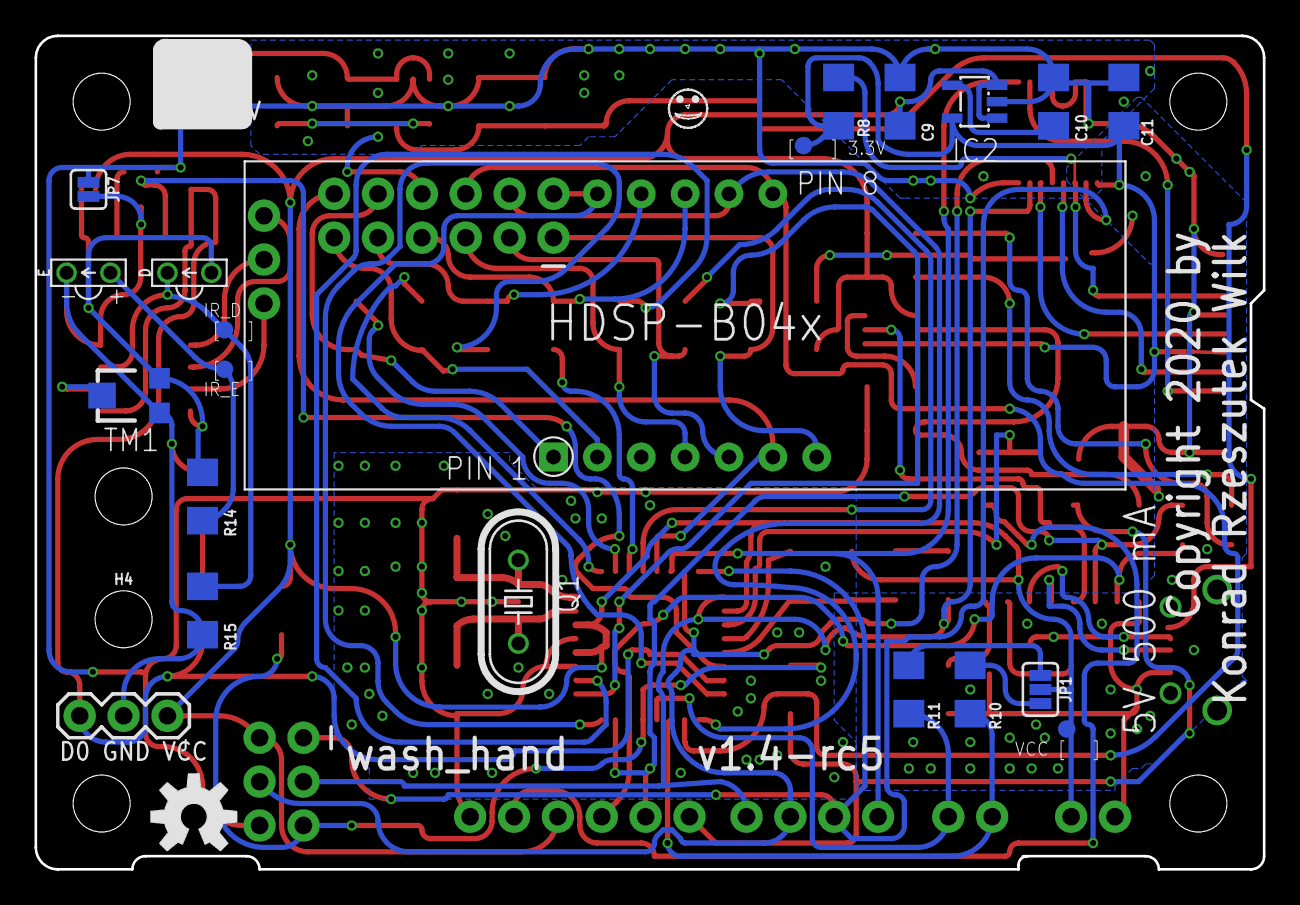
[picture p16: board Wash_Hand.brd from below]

Board: 2 copper layers, 71.1 x 48.3 mm, 91 parts (24 on the bottom side), 70 nets.

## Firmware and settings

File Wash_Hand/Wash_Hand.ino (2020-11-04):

/*
# Copyright 2020, Konrad Rzeszutek Wilk
# SPDX-License-Identifier: CC-BY-4.0
*/

#define DEBUG 1
#ifndef ARDUINO_AVR_NG
#define DEBUG_TIME 1
#endif
#define NOSD 1

#define STRINGIFY(x) #x
#ifndef USB
#include "func_gpio.h"
#else
#include "func_usb.h"
#endif

#ifndef NOSD
#include <SPI.h>
#include <SD.h>
#else
#endif

void write(char d1, char d2, char d3, char d4, unsigned int sleep) {

  writeD1(d1);
  delay(sleep);

  writeD2(d2);
  delay(sleep);

  writeD3(d3);
  delay(sleep);

  writeD4(d4);
  delay(sleep);
}

#include <avr/sleep.h>
#include <avr/wdt.h>

#ifdef DEBUG_TIME
volatile bool wdtFired;
unsigned long startTime = 0;
unsigned long endTime = 0;

ISR (WDT_vect)
{
   wdt_disable();  // disable watchdog
   wdtFired = true;
}  // end of WDT_vect

void setup ()
{
  noInterrupts ();           // timed sequence follows
  MCUSR = 0;
  // allow changes, disable reset
  WDTCSR = bit (WDCE) | bit (WDE);
  // set interrupt mode and an interval
  WDTCSR = bit (WDIE);    // set WDIE, and 16 ms seconds delay
  wdt_reset();  // pat the dog
  wdtFired = false;
  interrupts ();

  startTime = micros ();
  while (!wdtFired)
    { }  // wait for watchdog
  endTime = micros ();

}
#else
void setup (void) {

}
#endif

#define INIT  0

#define SOAP        (INIT+1)
#define SOAP_STR    'S','O','A','P'

#define WASH        (SOAP+1)
#define WASH_STR    'G','o','G','o'

#define COUNT       (WASH+1)
#define COUNT_MAX   (COUNT+20)

#define YAY         (COUNT_MAX+1)
#define YAY_STR     'Y','A','Y',' '

#define DONE        (YAY+1)
#define DONE_STR    'D','O','N','E'

#define CLEAR       (DONE+1)
#define CLEAR_STR   ' ',' ',' ',' '

#ifndef DEBUG
#define  DELAY 5
#define STR_DELAY 5000
#define SEC_DELAY 1000
#else
#define  DELAY 1
#define STR_DELAY 500
#define SEC_DELAY 100
#endif
#define DEBUG_STR   '1','2','3','8'

unsigned int state = INIT;
unsigned long s;

#ifndef NOSD
Sd2Card card;
SdVolume volume;
SdFile root;

const int CS = 10;
unsigned int done_sd = 0;
#endif
unsigned int waitFor(unsigned long timeout, unsigned new_state)
{
  unsigned long e = millis();

  if ((e - s) > timeout) {
    s = e;
    return new_state;
  }
  return state;
}


void printk(const char *str) {

  char *s;
  unsigned int i = 0;
  char buf[4] = {};

  s = (char *)str;
  do {
    if (*s) {
      buf[i] = *s;
      i++;
      s++;
    }
    if (i == 4 || *s == 0) {
      unsigned long _e, _s;

      _e = _s = millis();
      do {
        write(buf[0], buf[1], buf[2], buf[3], DELAY);
        debug_end();
        _e = millis();
      } while ( (_e - _s ) < STR_DELAY);

      buf[0] = buf[1] = buf[2] = buf[3] = ' ';
      i = 0;
    }
  } while (*s != 0);

}

void printk(unsigned long val) {

   char buf[8] = {};
   char dst[8] = {};
   unsigned int i = 0, j;
   unsigned int v;

   while (val > 0) {
     v = val % 10;
     buf[i]= '0' + v;
     val /= 10;
     if (val > 0)
        i++;
   }
   for (j = 0; j <= i; j++) {
     dst[j] = buf[i-j];
   }
   j++;
   dst[j++]='\0';
   printk(dst);
}

#define STR(x)  STRINGIFY(x)
#define ERR()   printk("ERR " STR(__LINE__));

#ifndef printf
#define printf(x) ;
#endif

unsigned int done = 0;
void loop() {
  int sensor = 0;
#ifdef DEBUG_TIME
  unsigned long delta;
#endif

  if (debug_loop() && !done) {
    setupPorts();
    printk("DBG");
#ifdef DEBUG_TIME
    printk("TIME");
    delta = (endTime - startTime);
    printk(delta);
#endif
    done = 1;
  }

#ifndef NOSD
  if (!done_sd) {
    setupPorts();

    if (!card.init(SPI_HALF_SPEED, CS)) {
      ERR();
    } else {
      switch (card.type()) {
        case SD_CARD_TYPE_SD1:
          printk("SD01");
          break;
        case SD_CARD_TYPE_SD2:
          printk("SD02");
          break;
        case SD_CARD_TYPE_SDHC:
          printk("SDHC");
          break;
        default:
          ERR();
          break;
      }
      if (!volume.init(card)) {
        ERR();
      } else {
        printk("OK!");
      }
    }
    done_sd = 1;
  }
#endif
  sensor = readSensor();
  if (sensor < 500) {
    if (state == INIT) {
        setupPorts();
        /* All of them cleared. */
        state = SOAP;
        s = millis();
    }
  }
  debug_begin(state);
  switch (state) {
    case SOAP:
      write(SOAP_STR, DELAY);
      state = waitFor(STR_DELAY, WASH);
      break;
    case WASH:
      write(WASH_STR, DELAY);
      /* This ends up jumping to the default case */
      state = waitFor(STR_DELAY, COUNT);
      break;
    case YAY:
      write(YAY_STR, DELAY);
      state = waitFor(STR_DELAY, DONE);
      break;
    case DONE:
      write(DONE_STR, DELAY);
      state = waitFor(STR_DELAY, CLEAR);
      break;
    case CLEAR:
      write(CLEAR_STR, 0);
      state = waitFor(10, INIT);
      break;
    case INIT:
      break;
    default:
      if ((state >= COUNT) && (state <= COUNT_MAX)) {
        unsigned int n = state - (COUNT);

        debug_print(n);

        if (n == 0) {
          state = state + 1;
        } else if (n <= 9) {
          writeD4('0' + n);
          state = waitFor(SEC_DELAY, state + 1);
        } else if ((n >= 10) && (n < 20)) {
          writeD3('1');
          delay(DELAY);
          writeD4('0' + n - 10);
          delay(DELAY);
          state=waitFor(SEC_DELAY, state + 1);
        } else if (n >= 20) {
          writeD3('2');
          delay(DELAY);
          writeD4('0'+ n - 20);
          delay(DELAY);
          state = waitFor(SEC_DELAY, state + 1);
        } else
          debug_error(STRINGIFY(__LINE__));

      } else if (state > COUNT_MAX) {
          state = YAY;
      } else {
          state = CLEAR;
      }
      break;
  }
  debug_end();
}

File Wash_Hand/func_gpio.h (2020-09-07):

/*
  Copyright 2020, Konrad Rzeszutek Wilk
  SPDX-License-Identifier: CC-BY-4.0
*/

#include "alpha.h"

#include "v1_3.h"

const uint16_t char_to_port[] = {
    pinA,
    pinB,
    pinC,
    pinD,
    pinE,
    pinF,
    pinG,
    pinDP,
};

void code(char c) {
  unsigned int i;
  unsigned int idx = (unsigned int)c - (unsigned int)' ';
  unsigned int val = SevenSegmentASCII[idx];

  for (i = 0; i < 7; i++) {
    if ((val & 1 <<i)) {
      digitalWrite(char_to_port[i], on);
    }
    else
      digitalWrite(char_to_port[i], off);
  }
}

void setupPorts() {

  pinMode(pinA, OUTPUT);
  pinMode(pinB, OUTPUT);
  pinMode(pinC, OUTPUT);
  pinMode(pinD, OUTPUT);
  pinMode(pinE, OUTPUT);
  pinMode(pinF, OUTPUT);
  pinMode(pinG, OUTPUT);
  pinMode(D1, OUTPUT);
  pinMode(D2, OUTPUT);
  pinMode(D3, OUTPUT);
  pinMode(D4, OUTPUT);

}

void writeD1(char d1) {
  digitalWrite(D1, off);
  digitalWrite(D2, on);
  digitalWrite(D3, on);
  digitalWrite(D4, on);
  code(d1);
}

void writeD2(char d2) {
  digitalWrite(D1, on);
  digitalWrite(D2, off);
  digitalWrite(D3, on);
  digitalWrite(D4, on);
  code(d2);
}

void writeD3(char d3) {
  digitalWrite(D1, on);
  digitalWrite(D2, on);
  digitalWrite(D3, off);
  digitalWrite(D4, on);
  code(d3);
}

void writeD4(char d4) {
  digitalWrite(D1, on);
  digitalWrite(D2, on);
  digitalWrite(D3, on);
  digitalWrite(D4, off);
  code(d4);
}

int readSensor(void) {

  return analogRead(BUTTON);
}

#ifdef DEBUG
static inline int debug_loop() { return 1; }
#else
static inline int debug_loop() { return 0; }
#endif

void debug_begin(unsigned int) {}
void debug_end(void) { }
void debug_print(unsigned int) { }
void debug_error(const char *) { }

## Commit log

2020-07-14 Initial schematic and board design.
    v1.1 is bad. I made the auto-routing , added some new items and it has
    now no linking to the schematic. Ignore it.
    v1.2 is the right one.
    [Wash_Hand_v1.1.brd, Wash_Hand_v1.1.sch, Wash_Hand_v1.2-routing.brd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]
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2020-07-14 Hardware: Copy v1.2 and fix up the libraries ..
    And also modify the version (1.2 -> 1.3).
    Keep in mind no routing has been done.
    [Wash_Hand_v1.3.brd, Wash_Hand_v1.3.sch]
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2020-07-23 Hardware: Split out using darnok_[common,led,usb] instead of the single one.
    As the darnok_misc is going away.
    [Wash_Hand_v1.3.brd, Wash_Hand_v1.3.sch]
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2020-07-23 Board: Moved all the SMD components to be behind the 7 Segment LED
    (Now that they are SMD they nicely fit behind it).
    [Wash_Hand_v1.3.brd]
2020-07-23 Hardware: Add resistors (4.7K) for the I2C along with a pad.
    The pad is there in case we don't want to use the pull-up
    resistors.
    [Wash_Hand_v1.3.brd, Wash_Hand_v1.3.sch]
2020-07-23 Board: Move the line sensor connectors down
    We still want the pins in case our design is no good.
    But the line sensor is 0.99 inch tall so we need to make
    sure we have enough space to fit this when the board
    becomes smaller.
    [Wash_Hand_v1.3.brd]
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2020-07-23 Hardware: VCC was NC
    Not sure how but VCC on USB was not connected to the rest of the VCC.
    [Wash_Hand_v1.3.brd, Wash_Hand_v1.3.sch]
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2020-07-23 Schematic: Move USB to make more space for adding a switch and 9V connection
    [Wash_Hand_v1.3.sch]
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2020-07-28 Hardware 1.2: Update the registers - it is 220Ohm, not 220K Ohm.
    I updated the Wash_Hand_v1.2-routing but forgot the primary one.
    [Wash_Hand_v1.2.brd, Wash_Hand_v1.2.sch]
2020-07-28 v1.2: Assembly notes.
    Biggest issues:
    - Missing PIN1 label on the ICSP header.
    - The ICSP header should be turned 90
    - Holes for the LED are mighty small
    - No 0.1 uF between pin 7,8 and 20,22
    - Putting in a ATMEGA328P from a Uno works, but programming via SPI no go.
    [Wash_Hand.ino]
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2020-07-29 Software: Fix the delay.
    The normal printing code needlessly delayed first, then
    selected the digit. With this we select the digit, then
    delay, and so on.
    [Wash_Hand.ino]
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2020-07-30 Software: Add debug_error to signal issues
    We should not hit those code paths - but if we do
    print out the line number.
    [func_gpio.h]
2020-07-30 Software: Fix the 0->19 number printing.
    Lets normalize it first, and _then_ print it out.
    Makes the logic simpler.
    [Wash_Hand.ino]
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2020-07-30 Software: Simplify the logic.
    Skip over 0 and modify the boundaries.
    [Wash_Hand.ino]
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2020-08-01 Revert of "Hardware: Switch to TQFP32 on ATMEGA328P"
    As I am not yet ready to switch to non-removable parts yet.
    [Wash_Hand_v1.3.brd, Wash_Hand_v1.3.sch]
2020-08-01 Schematic: Move the HDSP-B04E to v1.2 location.
    As we also want to re-use the same case for both versions.
    [Wash_Hand_v1.3.brd]
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2020-08-01 v1.3: Remove INT and DP connection, and attach A, B pins to
    [Wash_Hand_v1.3.brd, Wash_Hand_v1.3.sch]
2020-08-02 Board/Schematic: Add DTR label, add 0.1uF to RESET
    And also now add the DTR label to the ICSP header.
    [Wash_Hand_v1.3.brd, Wash_Hand_v1.3.sch]
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2020-08-03 Schematic: Use labels for D[1,2,3,4] for HDSP-B04E
    Way easier to see this than in prior versions.
    [Wash_Hand_v1.3.sch]
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2020-08-03 Board/Schematic: Added FTDI connector
    Had to move the other pieces around to make space for it.
    [Wash_Hand_v1.3.brd]
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2020-08-03 Board/Schematic: Add MIC5205 linear voltage regulator
    Which also meant we had to:
    - Move resistors and capacitors around.
    - Move on the schematic the components around.
    - Instead of a switch I just added a solder pad to isolate the USB when not needed.
    [Wash_Hand_v1.3.brd, Wash_Hand_v1.3.sch]
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2020-08-07 Board: Change to different line sensor.
    We are going to use discrete parts:
    - LTE-302, LTR-301 (IR emitter and detector).
    - TC33X-2-103E 10K pot
    - LM358DR
    - Bunch of SMD resistors
    This should us give better range.
    [Wash_Hand_v1.3.brd, Wash_Hand_v1.3.sch]
2020-08-08 Schematic: Add extra sheet.
    We can't just fit any more on just one.
    [Wash_Hand_v1.3.brd, Wash_Hand_v1.3.sch]
2020-08-08 Board/Schematic: Add test-points and adjust SMT to be aligned.
    Added TEST-POINT3X4 for:
    - TP1, 5V VCC
    - TP2, 5V USB VCC
    - TP3, IR Detector VCC
    - TP4, IR Emitter VCC
    - TP5, 9V VCC
    [Wash_Hand_v1.3.brd, Wash_Hand_v1.3.sch]
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2020-08-08 Board/Schematic: Add MicroSD card for reading data for display
    And that finishes v1.3 design.
    - Reworked connectors for programming via FTDI USB,
    - Built in line sensor,
    - Built in SD card for various texts,
    - SMD resistors and capacitors,
    - Test points,
    - 9V or 5V USB power option.
    Now off to debug design, BOM, then routing.
    [Wash_Hand_v1.3.brd, Wash_Hand_v1.3.sch]
2020-08-09 Board/Schematic: s/VCC/VCC label/
    As that makes it easier to switch in/out componets.
    [Wash_Hand_v1.3.brd, Wash_Hand_v1.3.sch]
2020-08-10 Schematic: Fix 4050 not having VCC or GND, add 0.1uF and 2.2uF to LM358
    [Wash_Hand_v1.3.brd, Wash_Hand_v1.3.sch]
2020-08-10 Board: Move parts around so capacitors are close to LP298 and MIC52055
    Both specs say that capacitors have to be within 0.5 inch.
    [Wash_Hand_v1.3.brd, Wash_Hand_v1.3.sch]
2020-08-10 Board: Rename VCC_JUMPER to EN_INT_SENSOR, D0_JUMPER, EN_INT_D0, and..
    .. move copyright and such around.
    Also add a text field around test spots.
    [Wash_Hand_v1.3.brd, Wash_Hand_v1.3.sch]
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2020-08-10 Board: Added pull-up resistor for MISO(D0) line.
    Various pages mention this is needed..?
    [Wash_Hand_v1.3.brd, Wash_Hand_v1.3.sch]
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2020-08-10 Board/Schematic: Add 470pF bypass to MIC5205
    And also change the Cout to be 2.2uF
    [Wash_Hand_v1.3.brd, Wash_Hand_v1.3.sch]
2020-08-11 Schematic: Add labels to parts around ATMEGA328P
    .. and also move the PINs and D[1-4] around.
    This does mean the software will have to change to deal with v1.3.
    As such lets just make it have it a v1_2.h to deal with older version.
    [Wash_Hand_v1.3.brd, Wash_Hand_v1.3.sch]
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2020-08-11 Board/Schematic: Add two test-points for Card Sensors.
    And also update the text around it.
    [Wash_Hand_v1.3.brd, Wash_Hand_v1.3.sch]
2020-08-12 Board: Move resistors to the bottom of to make space
    ..for a secondary TQFP ATMEGA 328P to be able to swap it in.
    [Wash_Hand_v1.3.brd]
2020-08-12 Board/Schematic: Add ATMEGA328P TQFP with goal of replacing DIP28
    .. so that we can swap in and out the DIP28 or TQFP for the prototype
    builds.
    [Wash_Hand_v1.3.brd, Wash_Hand_v1.3.sch]
2020-08-13 Schematic: Swap out Adafruit MicroSD for Amphenol 114-00841-68
    [Wash_Hand_v1.3.brd, Wash_Hand_v1.3.sch]
2020-08-15 Schematic: Fix C5 not being connected (found during routing).
    Somehow the lines did not connect so it just ended up being
    not connected. This fixes it.
    [Wash_Hand_v1.3.sch]
2020-08-15 Board: Routing #1
    - We moved a lot of resistors and capacitors around to be
    closer.
    - Realized we can do two "v1.3" - one with a DIP28 and
    one with TQFP. Most of the routes would hopefully lead to the
    right locations.
    [Wash_Hand_v1.3.brd]
2020-08-15 Revert of "Board/Schematic: Add ATMEGA328P TQFP with goal of replacing DIP28"
    .. albeit we still have all the parts in Schematic to
    nicely swap it out at the last minute.
    [Wash_Hand_v1.3.brd, Wash_Hand_v1.3.sch]
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2020-08-15 Revert: "Board/Schematic: Add ATMEGA328P TQFP with goal of replacing DIP28"
    .. with the rest of the items to not confuse readers.
    [Wash_Hand_v1.3.sch]
2020-08-15 Revert "Revert: "Board/Schematic: Add ATMEGA328P TQFP with goal of replacing DIP28""
    This reverts commit f9589984bb60b013662e24881b2ff85fb4deb026.
    [Wash_Hand_v1.3.sch]
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2020-09-02 Board: Fix up the URL and make date automatic.
    The URL is to the GitHub. And for date lets use LAST_DATE_TIME.
    Sadly for REVISION we still need to manually edit the board.
    [Wash_Hand_v1.3.brd, Wash_Hand_v1.3.sch]
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2020-09-02 Board: Add place to drop red resin for version
    During the assembly phase we want to mark the assembly
    number. Problem is if we use a marker it gets washed
    away so we can use the red resin in these spots to write
    a 8 bit number using dots. Along with a note space for
    extra space if we can figure out a non-alchol washable pen.
    [Wash_Hand_v1.3.brd]
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2020-09-02 Board: Fixup DRC errors marked
    [Wash_Hand_v1.3.brd]
2020-09-02 Board/Schematic: Swap out 4050 to 16TSSOP
    instead of the more bulkier SOP16
    [Wash_Hand_v1.3.brd, Wash_Hand_v1.3.sch]
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2020-09-03 Board/Schematic: Replace C8 with C11 to make it easier to read.
    [Wash_Hand_v1.3.brd, Wash_Hand_v1.3.sch]
2020-09-03 Board/Schematic: Add + and - to LM358
    No clue how we missed that .. but we did.
    [Wash_Hand_v1.3.brd, Wash_Hand_v1.3.sch]
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2020-09-05 ERC: Approve errors about 0 being used as multiple outputs
    As 0 in this case is GND.
    [Wash_Hand_v1.3.sch]
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2020-09-07 Software: Fix the warnings over __LINE__
    [Wash_Hand.ino, func_gpio.h]
2020-09-07 v1.3b: Start notes on the assembly of it/rework needed.
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2020-09-14 Makefile: Add TQFP and DIP28 ZIF upload..
    I've two Arduino Shields with a ZIF and TQFP socket
    on them and this is to upload code using:
    Arduino UNO -> ZIP socket
    .. but I always seem to get verification failures, not
    sure if that is the chip itself or the setup.
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2020-09-15 Board/Schematic: Fix the 16MHz/10pF capacitors.
    The way they are were in the schematic looked right.
    Two capacitors off the crystal. Both capacitors go to
    ground. Except that what Eagle decided it should be was:
    XTAL1 XTAL2
    | |
    +--[CRYSTAL]--+
    [CAP]
    |
    [CAP]
    |
    [GND]
    Instead of the:
    XTAL1 XTAL2
    | |
    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
    [Wash_Hand_v1.3.brd, Wash_Hand_v1.3.sch]
2020-09-15 Board/Schematic: Use RESET instead of DTR on ICSP
    We don't want the line past the 0.1uF cap to go
    in the ICSP but instead use the one that goes directly
    to the RESET pin.
    [Wash_Hand_v1.3.brd, Wash_Hand_v1.3.sch]
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2020-09-15 Board: Swap C7 with C9.
    The LP298 has C9,C10,C11 but in the board right next to it are:
    _C7_,C10,C11!
    The MIC5205 has C5,C6,C7,C8 but in the board right next to it
    are: C5,C6,_C9_, and C8.
    Lets swap them around to be closer to their own circuits.
    [Wash_Hand_v1.3.brd]
2020-09-15 Board/Schematic: Swap names (and values)of C6 and C7
    They are right next to each other - and we want
    the 1uF to be closer to MIC5205.
    It was easier to swap the names than moving
    the SMD on the board.
    [Wash_Hand_v1.3.brd, Wash_Hand_v1.3.sch]
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2020-09-22 Board/Schematic: Major rework:
    - Move the TQFP so that we can have the crystal right next to it.
    - Move most of the data lines to one side of the board.
    - Move resistors / capacitors around around the components
    - Make the wires 0.012 instead of 0.006 (or 0.008).
    - Also while we are it, make the turns more curved.
    Next:
    - Flip the 7Digit resistors to be the other side (right now
    they are under the segment display)
    - Add ground plane.
    [Wash_Hand_v1.3.brd, Wash_Hand_v1.3.sch]
2020-09-22 Board: Flip 7Segment resistors
    .. and also some DRC errors.
    [Wash_Hand_v1.3.brd]
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2020-09-22 Board: Add some vias for ground and fixups
    some of the tracing was of smaller size.
    [Wash_Hand.brd]
2020-09-22 Board: Fix up the wires to be 0.012
    [Wash_Hand.brd]
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2020-09-22 Board: Fix up the Test sites (it moved to back )
    [Wash_Hand.brd]
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2020-09-22 Board: Fixup the registers name and values.
    Align the names and values to be next to each other.
    [Wash_Hand.brd]
2020-09-22 Board: Flip R9 around.
    We don't want too many optional components on the back
    to easy the production runs (as we have to use red
    resin to glue it).
    [Wash_Hand.brd]
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2020-09-24 Board/Schematic: Replace open with closed SMT pads for line sensor
    As we want it by default enabled.
    [Wash_Hand.brd, Wash_Hand.sch]
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2020-09-24 Board/Schematic: Replace 9V/5V SMT pad with normally closed
    Makes it easier to debug as the solder will close both
    of. But if we are doing production runs we would enable/disable
    the connectors by not populating the components (like the
    whole 9V power-plant).
    [Wash_Hand.brd, Wash_Hand.sch]
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2020-09-25 Board/Schematic: Replace test-pad for USB-5V with 1X1 pin
    It makes it much easier to test without having to solder
    the USB connector.
    [Wash_Hand.brd, Wash_Hand.sch]
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2020-11-04 Software: ATMEGA8 fails when compiling with WDT timer
    .. as that seems to not be defined in include files.
    [Wash_Hand.ino]
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2020-12-08 Board/Schematic: Swap TX/RX on CH340G
    .. as they are inversed.
    [Wash_Hand.brd, Wash_Hand.sch]
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2020-12-08 Board/Schematic: Line Sensor: Swap 10K with PIR sensor
    I had the 10K with PIR sensor inverted. That is
    the voltage would go down when we are in dark room (so
    nothing to detect), and go above the Vref (aka the
    10K pot on NEG_IN) and light up the LED.
    We need it the other way around - that is in dark
    rooms (so PIR is 20K ohm ,or 7.8K ohm) we want the
    voltage to be below the Vref (NEG_IN), and only go
    high when the 940nm light emitter is reflected and
    PIR is around 300ohm.
    PIR ohm| 10K | voltage|conditions
    ---+-----+------------+----------
    300 | 10K | 4.8V | light reflected
    7.8K | 10K | 3.6V | daylight
    20K | 10K | 1.6V | dark night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
    [Wash_Hand.brd, Wash_Hand.sch]
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2020-12-11 Board/Schematic: Add 1.2K resistor to transistor - in correct place
    This fixes the "Board/Schematic: Add 1.2K resistor to transistor" and
    adds the resistor on the correct side of the transitor.
    [Wash_Hand.brd, Wash_Hand.sch]
2020-12-27 Board/release/3d: Add housing to the exported images..
    which along with the dimensions can be exported to BMP
    and then converted to STL files for helping to create
    a box for it.
    The sequence is as follow:
    - Install Inkscape 0.92 (don't use 1.01) as the extension does not work
    with later versions.
    - Install in .config/inkscape/extensions the
    https://github.com/l0b0/paths2openscad.git extension
    (the .py and .inx file).
    - In Inkscape import the SVG file (created from the
    release.sh - the h-<release>.svg file. (See Wash_Hand_dim.svg)
    - Select All
    - Extensions|Generate from Path|Paths to OpenSCAD
    - Output file Wash_Hand_dim.scad, keep the defaults, let it rip
    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
    [Wash_Hand.brd, Wash_Hand_dim.scad, Wash_Hand_dim.stl]
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2020-12-28 3d: Fix script and expand instructions
    .. we needed to print it in monochrome (black and white)
    for the tool to pick up the lines.
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2021-04-17 Board/Design: Replace PNP with NPN
    And also re-route the ground since the NPN will now
    control whether this whole thing is going to be on/off.
    [Wash_Hand.brd, Wash_Hand.sch]
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2021-04-20 Board/Schematic: Re-orient LED1 to face correctly.
    It was turned around.
    [Wash_Hand.brd, Wash_Hand.sch]
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2021-04-21 BOM: Swap out ATMEGA328 with ATMEGA8
    since we don't need all that processing power
    on this revision.
    [BOM.csv]
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2021-04-22 BOM: Swap out CH340G to Jiangsu Qin Heng
    [BOM.csv]
2021-05-08 BOM: Fix the incorrect field.
    [BOM.csv]
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

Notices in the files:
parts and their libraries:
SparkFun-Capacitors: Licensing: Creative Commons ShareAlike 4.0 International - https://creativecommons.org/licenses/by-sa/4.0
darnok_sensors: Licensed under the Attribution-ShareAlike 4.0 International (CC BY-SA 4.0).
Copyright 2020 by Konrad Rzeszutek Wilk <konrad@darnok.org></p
